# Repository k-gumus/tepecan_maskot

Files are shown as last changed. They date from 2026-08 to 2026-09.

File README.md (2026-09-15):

# Tepecan

Yeditepe IEEE kulübünün resmi maskotu — 3D baskı gövde ve içine giren sesli
asistan. Dinler, sorulanı yapay zekâya iletir, cevabı Türkçe olarak
hoparlöründen söyler.

<p align="center">
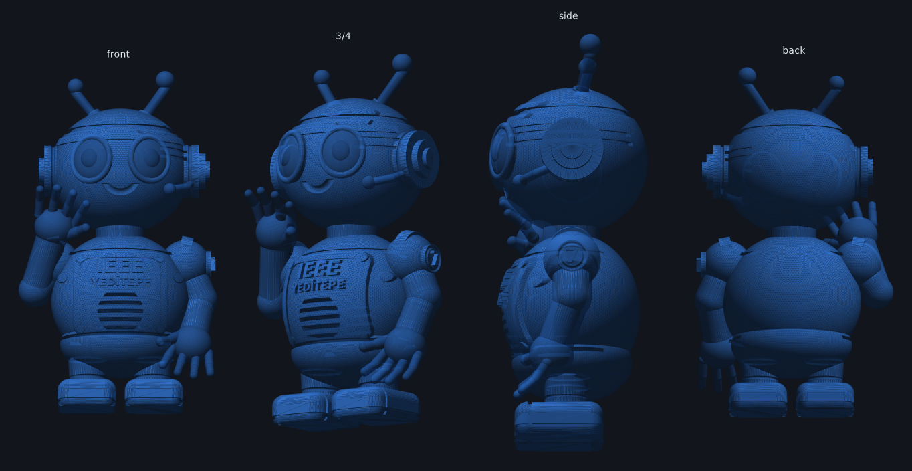
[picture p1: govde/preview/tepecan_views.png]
  
</p>

- **240 mm** boy, tek parça basılan gövde
- Sırtta **vidalı kapak** (73 × 62 mm açıklık), içinde 90 × 75 × 87 mm bölme
- Göğüste kabartma **IEEE** ve **YEDİTEPE**, sol omuzda **7** rozeti
- **"Hey Tepecan"** ile butonsuz tetikleme (yerel, openWakeWord)
- Beyin ağdaki bir PC'de çalışır: **token maliyeti yok, internet gerekmez**

---

## Depoda ne var

```
govde/        3D model — parametrik script, baskıya hazır STL'ler, önizlemeler
yazilim/      esp32/ (maskotun içindeki firmware) ve sunucu/ (ses↔metin↔cevap)
dokuman/      yapım kılavuzu (PDF), bağlantı şeması, üretim scriptleri
```

**Başlarken okunacak tek dosya:** [`dokuman/Tepecan_Yapim_Kilavuzu.pdf`](dokuman/Tepecan_Yapim_Kilavuzu.pdf)
— malzeme listesinden montaja, kuruluma ve sorun gidermeye kadar her şey orada.

---

## Nasıl çalışıyor

```
   MASKOT (ESP32-S3)                       BEYİN SUNUCUSU (bir PC)
   "Hey Tepecan" / buton
   mikrofon kaydeder      ──── Wi-Fi ───▶  /stt    faster-whisper   (ses → metin)
                                           :11434  Ollama, qwen3:4b (cevabı üretir)
   hoparlör çalar         ◀─── Wi-Fi ────  /tts    Piper            (metin → ses)
```

Maskotun içindeki kartın tek işi mikrofonu okuyup hoparlöre yazmak. Ses→metin,
dil modeli ve metin→ses, ağdaki bir bilgisayarda çalışır. Bu yüzden 512 MB
RAM'li küçük bir kart yetiyor ve kullanım başına maliyet oluşmuyor.

Cevap tamamlanmadan konuşmaya başlar: model ilk cümleyi bitirir bitirmez o
cümle seslendirilir, kalanı arka planda üretilir.

<p align="center">
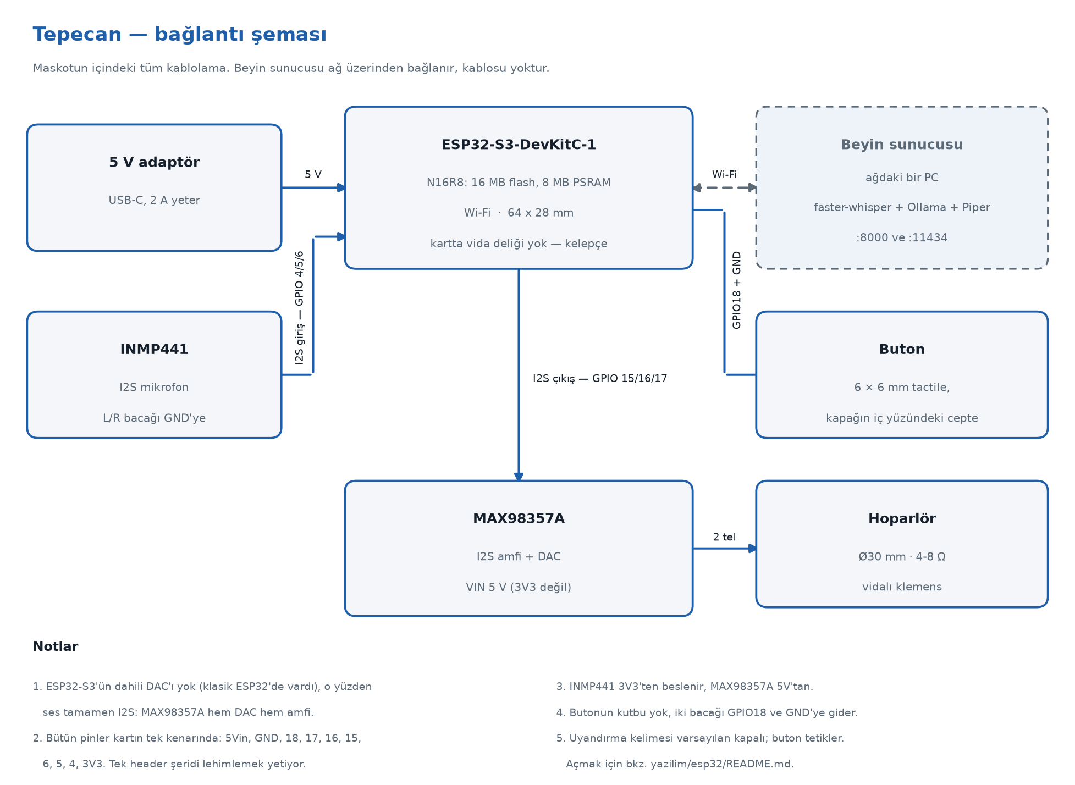
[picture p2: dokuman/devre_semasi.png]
  
</p>

---

## Gövde

```bash
cd govde
pip install -r requirements.txt
python3 tepecan_model.py                 # 240 mm, stl/ klasörünü üretir
python3 tepecan_model.py --height 180    # daha küçük baskı, cidar yine 3 mm
python3 preview_render.py                # önizleme görselleri
python3 dogrula.py                       # elektronik gerçekten sığıyor mu
```

| Dosya | Ne |
|---|---|
| `stl/tepecan_body.stl` | İçi boş gövde — sırt açıklığı, kapak kenarı, vida boss'ları, hoparlör adası, kart kuleleri |
| `stl/tepecan_lid.stl` | Sırt kapağı, baskı pozisyonunda |
| `stl/tepecan_buton.stl` | Kapaktaki butonun kapağı (Ø10 mm başlık, 5 mm sap) |
| `stl/tepecan_plaka.stl` | Kart tepsisi (72 × 36 × 3 mm, ~20 dk) |
| `stl/tepecan_solid.stl` | İçi dolu vitrin figürü (elektronik yoksa bunu bas) |
| `stl/tepesu.stl` | Tepesu: elektroniksiz ikiz, kaldırdığı elinde QR kartı klipsi |

Figür tasarım biriminde modellenip export'ta ölçekleniyor; cidar kalınlığı,
vida delikleri ve kapak boşluğu gibi mutlak kalması gereken ölçüler önce bu
ölçeğe bölünüyor — böylece M3 vida her boyda M3 kalıyor.

Script her STL'i yazdıktan sonra dosyayı geri okuyup kapalı (watertight),
tutarlı normalli, tek parça ve pozitif hacimli olduğunu doğruluyor; geçmezse
hata verip duruyor.

`dogrula.py` bir adım öteye gidiyor: gerçek parçaların zarflarını (65 × 30 × 18 mm
kart, Ø30 mm hoparlör, 6 × 6 × 4.3 mm switch) basılmış STL'in içine yerleştirip
boolean kesişime bakıyor. Sıfır olmayan her kesişim, o parçanın gövdeye girmediği
anlamına geliyor. Hangi kartın alınacağı belli olmadığı için kavitenin kabul
ettiği en büyük kart zarfını da ölçüp yazdırıyor.

**Kart gövdeye kilitli değil.** Gövdede yalnız genel amaçlı dört kule var;
karta özel her şey ayrı basılan `tepecan_plaka.stl` tepsisinde. Kart
değişirse 30-45 saatlik gövde değil, 20 dakikalık tepsi yeniden basılıyor —
`BOARD_HOLE_X` / `BOARD_HOLE_Y` (gerekirse `BOARD_OFFSET_Y`) değiştirilip
yeniden üretiliyor.

| İç ölçü | Değer |
|---|---|
| Kapak açıklığı / geçiş | 73 × 62 mm / 65 × 54 mm |
| Gövde kuleleri | Ø6 mm, 44 × 28 mm aralık (karttan bağımsız), üstleri tabandan 63.8 mm'de |
| Kule kılavuz deliği | Ø2.1 mm × 8 mm (M2.5 kendinden kılavuzlu) |
| Kart tepsisi | 72 × 36 × 3 mm, kart kelepçeyle bağlanıyor |
| Kart için yer | 69.5 × 30, 63.4 × 40-55 mm; tepsi üstünde 40 mm yükseklik |
| Hoparlör yuvası | ızgara Ø30 mm, cep Ø32 mm, düz omuz |
| Kapak vidası | 2 × M3, Ø18.7 mm boss, 12 mm derin |
| Buton | kapakta, Ø4.2 mm delik + 6.6 mm kare cep |
| Kablo yuvası | 15.6 × 7.8 mm, tabandan 38 mm'de |
| Cidar | 3 mm |

**Baskı:** PLA, 0.20 mm katman, 3 perimetre, %10-15 dolgu, ağaç destek açık,
5 mm brim. Z ekseni ≥ 250 mm olan yazıcı gerekiyor.

---

## Yazılım

**Sunucu** (kulüpteki PC):

```bash
curl -fsSL https://ollama.com/install.sh | sh
ollama pull qwen3:4b
OLLAMA_HOST=0.0.0.0 ollama serve

cd yazilim/sunucu
pip install -r requirements.txt
uvicorn beyin:app --host 0.0.0.0 --port 8000
```

**Maskot** — ESP32-S3 (`yazilim/esp32/`, ESP-IDF):

```bash
cd yazilim/esp32
idf.py set-target esp32s3 && idf.py build
idf.py -p /dev/ttyUSB0 flash monitor
```

Wi-Fi bilgisi koda gömülü değil: kart ilk açılışta `Tepecan-Kurulum`
erişim noktasını açıyor, telefondan `http://192.168.4.1` üzerinden ağ ve
sunucu adresi giriliyor. Ayrıntılar ve uyandırma kelimesi modelinin
eğitimi: [`yazilim/esp32/README.md`](yazilim/esp32/README.md).

Sırt kapağındaki **butona bas** — kayıt sen susunca kendiliğinden biter.
**"Hey Tepecan"** ile uyandırma da kodda var ama varsayılan kapalı: ifadeye
özel eğitilmiş bir microWakeWord modeli gerekiyor. Açma yolu ve model eğitimi
[`yazilim/esp32/README.md`](yazilim/esp32/README.md) içinde.

### Ayarlar

| Değişken | Varsayılan | Ne işe yarar |
|---|---|---|
| `TEPECAN_BRAIN` | `http://tepecan-beyin.local` | Beyin sunucusunun adresi |
| `TEPECAN_MODEL` | `qwen3:4b` | Ollama'da kullanılacak model |
| `TEPECAN_LLM_BACKEND` | `ollama` | `ollama` veya `claude` |
| `TEPECAN_BUTTON_PIN` | `17` | Butonun bağlı olduğu GPIO |
| `TEPECAN_WAKE_MODEL` | `~/tepecan/hey_tepecan.onnx` | Uyandırma modeli; yoksa sadece buton |
| `TEPECAN_WAKE_THRESHOLD` | `0.5` | Uyandırma eşiği (yükselt = az yanlış tetikleme) |
| `STT_MODEL` / `STT_DEVICE` | `small` / `cpu` | Sunucuda whisper boyutu ve cihazı |
| `PIPER_MODEL` | `~/piper/tr_TR-dfki-medium.onnx` | Sunucuda Türkçe ses modeli |

### Küçük modelden iyi cevap almak

Model 4 milyar parametreli; ondan bilgiyi *bilmesini* değil, verdiğimiz metni
*okumasını* istiyoruz. Kaliteyi belirleyen sıra:

1. **`yazilim/sunucu/bilgiler.txt` dosyasını doldur.** Kulübe dair her gerçek
   buraya; her soruda modele veriliyor. Doğru cevabı sağlayan asıl mekanizma bu.
2. `persona.txt` içindeki 2-3 cümle sınırını gevşetme — küçük modeller
   uzadıkça dağılır.
3. Hafıza 6 mesajla sınırlı ve 3 dakika sessizlikte sıfırlanıyor; artırma.

---

## Lisans

MIT — bkz. [LICENSE](LICENSE).

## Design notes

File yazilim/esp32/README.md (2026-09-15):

# Tepecan — ESP32-S3 istemcisi

Maskotun içindeki kart. Mikrofonu dinler, uyandırma kelimesini yakalar,
beyin sunucusuna gönderir, gelen cevabı hoparlörden çalar. Ses-metin, dil
modeli ve metin-ses bu kartta değil — hepsi `yazilim/sunucu/beyin.py`'de.

**Donanım:** ESP32-S3-DevKitC-1 N16R8 (16 MB flash, 8 MB PSRAM) ·
INMP441 I2S mikrofon · MAX98357A I2S amfi · Ø30 mm 4 Ω hoparlör ·
6×6 mm tactile switch.

PSRAM şart: kayıt tamponu ve Piper'dan gelen WAV orada duruyor.

## Bağlantılar

| Modül | Bacak | ESP32-S3 |
|---|---|---|
| INMP441 | VDD | 3V3 |
| | GND, L/R | GND |
| | SCK | GPIO4 |
| | WS | GPIO5 |
| | SD | GPIO6 |
| MAX98357A | VIN | **5V** (3V3 değil) |
| | GND | GND |
| | BCLK | GPIO15 |
| | LRC | GPIO16 |
| | DIN | GPIO17 |
| Buton | bacak 1 | GPIO18 |
| | bacak 2 | GND |
| Hoparlör | +/− | MAX98357A çıkışı |

INMP441'in **L/R bacağı GND'ye** gitmeli — sol kanaldan konuşsun diye;
kod da sol kanalı okuyor. Pinleri değiştirmek istersen `main/tepecan.h`.

## Derleme ve yükleme

ESP-IDF v5.1 veya üstü gerekiyor; v5.3 ve v6.1 ile derlendiği doğrulandı.

```bash
idf.py set-target esp32s3
idf.py build
idf.py -p /dev/ttyUSB0 flash monitor
```

> DevKitC-1'de **iki USB-C portu** var (biri native USB, biri UART).
> Yükleme olmazsa diğerini dene — en çok takılınan yer burası.

Windows'ta projeyi **ASCII bir yola** koy (`C:\esp\tepecan` gibi): ESP-IDF
Türkçe karakterli yollarda (`Masaüstü`) takılıyor, OneDrive içinde derlemek de
dosya kilidi sorunları çıkarıyor.

Bağımlılıklar (`esp-tflite-micro`, `esp-nn`, `esp-micro-speech-features`)
`main/idf_component.yml` ile otomatik iniyor, elle bir şey kurmana gerek yok.

## İlk kurulum — bilgisayara gerek yok

Wi-Fi bilgisi koda gömülü değil. Kart kayıtlı ağ bulamazsa kendi erişim
noktasını açıyor:

1. Telefondan **`Tepecan-Kurulum`** ağına bağlan (şifresiz).
2. Tarayıcıda `http://192.168.4.1` aç.
3. Wi-Fi adı, şifresi ve beyin sunucusunun adresini gir.
4. Kaydet — kart yeniden başlayıp o ağa bağlanıyor.

Bilgiler NVS'e yazılıyor, sonraki açılışlarda kendi bağlanıyor. Kulüpten
etkinliğe geçerken ağ değiştirmek için de aynı portal yeter; USB yalnız
ilk yüklemede lazım.

## Uyandırma kelimesi

"Hey Tepecan" modeli depoda **yok**, olamaz da: microWakeWord modelleri
söylenen ifadeye özel eğitiliyor. Kart model dosyası olmadan da çalışır —
o zaman yalnız sırt kapağındaki buton tetikler.

Model eğitmek için:

1. <https://microwakeword.com/train> üzerinden "Hey Tepecan" ifadesini
   eğit (Colab defteri, ücretsiz GPU ile birkaç saat).
2. Çıkan `.tflite` dosyasını `hey_tepecan.tflite` diye adlandır.
3. `model` bölümüne yükle:
   ```bash
   mkdir -p spiffs && cp hey_tepecan.tflite spiffs/
   idf.py storage-flash        # ya da: parttool.py write_partition --partition-name=model
   ```

Dürüst uyarı: microWakeWord'ün kendi belgeleri *"iyi çalışan bir model
eğitmek hâlâ çok zor, ileri seviye kullanıcılar için"* diyor. İlk denemede
tutmayabilir. Yanlış tetikleme çoksa `tepecan.h` içinde `WAKE_ESIK`'i
yükselt (0.85 → 0.92) ya da `WAKE_ARDISIK`'ı 3 yap; hiç tetiklemiyorsa tersi.

Hazır bir modelle zinciri denemek istersen
<https://microwakeword.com/library> altında topluluk modelleri var.

## Ayarlar

Hepsi `main/tepecan.h` içinde: pinler, örnekleme hızı, sessizlik eşiği,
uyandırma eşiği, varsayılan sunucu adresi.

`main/ses.c` içindeki `ses_var_mi()` basit bir RMS eşiği (500) kullanıyor.
Oda gürültülüyse kayıt hiç bitmiyor olabilir — eşiği yükselt. Çok sessizse
ve kayıt erken kesiliyorsa düşür.

## Bilinmesi gerekenler

- **Bu kod donanım üzerinde denenmedi.** Elimde kart yokken yazıldı;
  ilk yüklemede I2S pin/kanal ayarlarında düzeltme gerekebilir. En olası
  yer: INMP441'in kanal seçimi (`MIC_KANAL_SOL`) ve kazanç kaydırması
  (`ses.c` içinde `>> 11`) — ses çok kısık ya da bozuk gelirse orası.
- Beyin sunucusu açık olmalı. Kart ona ulaşamazsa duyar ama cevap veremez.
- MAX98357A pille çalışırken 5 V yerine 3.7-4.2 V görür, ses biraz kısılır.

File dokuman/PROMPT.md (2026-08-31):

# Tepecan için hazır prompt'lar

## 1) AI 3B model araçları (Meshy / Tripo / Sloyd / Rodin) — görselden model

Bu araçlara `reference/tepecan_reference.jpg` görselini **image-to-3D** modunda
yükleyin, ardından açıklama alanına:

> Chibi mascot robot character, full body, standing, with the
> right arm raised in a fist. Big round helmet-like head, two large oval anime
> eyes with raised metallic rims, small curved smile, two thin antennae with
> spherical tips, round headphone/camera discs on both sides of the head.
> Rounded egg-shaped torso with a flat chest panel, short stubby arms with
> mitten fists, short legs with chunky flat-bottomed boots. Smooth hard-surface
> plastic robot toy, closed clean surfaces, no thin fins, no floating parts,
> no text. Single watertight solid, manifold, printable, flat base.
> Style: vinyl designer toy / collectible figurine.

Negatif prompt (destekliyorsa):

> thin fragile parts, floating geometry, holes in surface, open shell,
> hair strands, cloth, sharp spikes, text, logos

Sonrasında **Remesh → Watertight/Solid** ve **Export → STL (mm)** seçin,
yüksekliği 150 mm'ye ölçekleyin. Bu araçlar içi boş bölme ve vida kulağı
üretmez; onu Blender/Fusion/Tinkercad'de eklemek gerekir (bkz. 2. prompt).

## 2) Kod üreten bir asistana (Claude / ChatGPT) — parametrik ve kesin sonuç

> Write a Python script using trimesh + manifold3d that builds a 3D-printable
> chibi mascot robot and exports STL files. Build everything with CSG on
> watertight primitives (icospheres scaled into ellipsoids, capsules, rounded
> boxes made from convex hulls of corner spheres) so the result is manifold.
>
> Figure (design units, Z up, +Y = front): egg-shaped torso ellipsoid
> r=(31,26,30) at z=52 plus a hip ellipsoid r=(27,23,15) at z=32; head
> ellipsoid r=(31,29,28) at z=110; two eye ellipsoids r=(9,7.5,10.5) at
> (±13,21.5,112) with torus rims and raised iris discs; a shallow smile groove
> cut with a torus arc; headphone/camera discs on both sides of the head; a
> microphone boom; two antennae with ball tips and collars; stubby arms with
> ball fists, one raised; short legs with rounded-box boots; the base sliced
> flat at z=2. Natural height ~154 units; scale the exported meshes so the
> printed figure is 240 mm tall.
>
> Add surface detail by intersecting thin offset shells of a body with slabs
> and prisms: a helmet seam and vent lines on the head, a brow ridge, panel
> lines on the belly and chest, ring grooves at every elbow, wrist and knee,
> sole and toe seams on the boots, a raised chest panel with a recessed field
> carrying embossed "IEEE" and "YEDİTEPE", rivet studs, and a numbered badge
> disc on the left shoulder.
>
> Then make an electronics compartment: hollow the torso with an inner
> ellipsoid one wall thickness smaller (wall 3 mm at the printed size), cut a
> 38 x 40 unit rounded opening in the back, add a seating ledge that reaches
> into the opening, add two screw bosses with 2.7 mm pilot holes, and cut a
> cable slot below the opening. Build the cover as the intersection of the
> torso shell with the opening prism shrunk by 0.6 units (0.3 mm clearance per
> side), give it a raised border frame, three vent slots and countersunk
> 3.5 mm clearance holes.
>
> Keep wall thickness, screw holes and cover clearance absolute in mm: divide
> them by the export scale factor before building, so an M3 screw stays M3 at
> any figure height.
>
> Export tepecan_solid.stl (display figure), tepecan_body.stl and
> tepecan_lid.stl (cover rotated flat for printing). Round vertices to float32
> before writing (that is what STL stores), drop the zero-volume shells that
> booleans leave at tangent surfaces, then read each file back and assert it is
> watertight, winding-consistent, a single connected component and of positive
> volume.

Bu depodaki `tepecan_model.py` tam olarak bunun sonucudur; istersen doğrudan
onu çalıştırmak en hızlısı.

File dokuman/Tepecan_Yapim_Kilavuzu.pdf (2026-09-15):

# TEPECAN

# Konuşan maskot — yapım kılavuzu

## 3D baskı gövde · ESP32-S3 · yerel yapay zekâ · Türkçe sesli sohbet

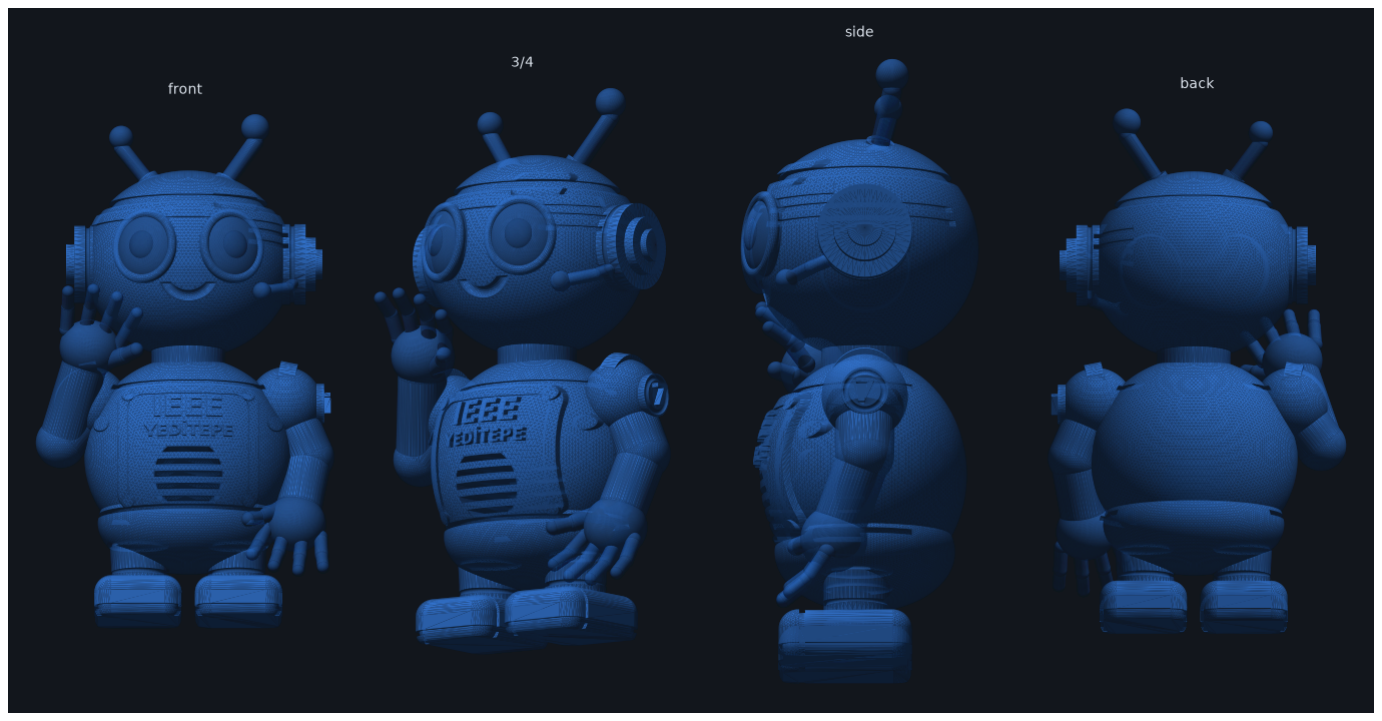
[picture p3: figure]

Tepecan — konuşan maskot yapım kılavuzu | 2

# 1. Ne yapıyoruz

Maskot dinler, sorulanı yapay zekâya iletir, cevabı içindeki hoparlörden Türkçe olarak söyler. Ağır iş maskotun içinde değil, ağdaki bir bilgisayarda çalışır. Maskotun içindeki kartın tek görevi mikrofonu okumak ve hoparlöre yazmak — bu sayede 512 MB RAM'li küçük bir kart yeter ve token maliyeti oluşmaz.

MASKOT (ESP32-S3) | BEYİN SUNUCUSU (bir PC)
───────────────────── | ────────────────────────
butona basılır
mikrofon kaydeder | ──── Wi-Fi ───▶ | /stt | faster-whisper | (ses → metin)
:11434 | Ollama, qwen3:4b (cevabı üretir)
hoparlör çalar | ◀─── Wi-Fi ──── /tts | Piper | (metin → ses)

Cevap tamamlanmadan konuşmaya başlar: model ilk cümleyi bitirir bitirmez o cümle seslendirilir, kalanı arka planda üretilir. Algılanan gecikmeyi yarıya indiren tek değişiklik budur.

## Verilen kararlar ve gerekçeleri

Karar | Neden
Beyin ayrı bir PC'de | Bu sınıf kartlarda 512 MB - 2 GB RAM var; en küçük dil modeli bile zor sığar,
sığsa saniyede 1-3 token üretir. Bir cümle yarım dakika sürerdi.

Büyük kart alınmıyor 85 × 56 mm bir kart maskotun içine girmiyor: kapak açıklığının köşegeni 85.1 mm, o kartın köşegeni 85.8 mm. Kapalı PLA kasada da ısınıyor. Çözdüğü tek darboğaz zaten sunucuya taşındı.

Linux kartı yerine
ESP32-S3

Raspberry Pi de, muadil aarch64 kartlar da Türkiye'de bulunamadı; ESP32-S3 her yerde var ve üçte bir fiyatta. Kart zaten ince istemci olduğu için işletim sistemine ihtiyaç yok: SD kart, açılış süresi ve sürücü avı tamamen kalkıyor.

Ses I2S üzerinden | ESP32-S3'ün dahili DAC'ı yok (klasik ESP32'de vardı, S3'te kaldırıldı), yani
analog çıkış seçenek değil. MAX98357A hem DAC hem amfi olduğu için tek modülle çözülüyor.

Metin → ses de
sunucuda

Piper'ın Türkçe medium sesi Zero 2 W'de gerçek zamandan yavaş kalabiliyor. Sunucuda çalıştırınca bu risk tamamen kalkar, Pi'ye hazır ses gelir.

Model: Qwen3 4B | Küçük modeller arasında çok dilli tarafı güçlü olanlardan; Türkçesi
kullanılabilir. Gemma 3 4B ikinci aday, karşılaştırmaya değer.

Uyandırma kelimesi +
buton

"Hey Tepecan" ile butonsuz tetikleme (openWakeWord, yerel). Metin→ses sunucuya taşındığı için Pi'de yer açıldı. Buton yedek olarak duruyor: gürültülü stantta uyandırmayı kapatıp butona dönebilirsin.

Ollama +
faster-whisper + Piper

Üçü de ücretsiz ve yerel. Zincirin tamamı internetsiz çalışır, kullanım başına maliyet yoktur.

# 2. Malzeme listesi

Fiyatlar kabaca, sadece büyüklük fikri versin diye.

# | Parça | Neden bu | ≈

1 | ESP32-S3-DevKitC-1, N16R8 | Maskotun beyni değil, kulağı ve ağzı: mikrofonu dinler, beyin sunucusuna gönderir, gelen cevabı çalar. N16R8 varyantı şart — 8 MB PSRAM'de kayıt tamponu ve Piper'dan dönen WAV duruyor. 64 × 28 mm, montaj deliği yok (tepsiye kelepçeyle bağlanıyor). | $8
2 | INMP441 I2S mikrofon modülü

Dijital çıkışlı, doğrudan karta bağlanıyor. L/R bacağı GND'ye gider, kod sol kanalı okuyor.

$3

3 MAX98357A I2S amfi modülü

Hem DAC hem 3 W sınıf-D amfi. ESP32-S3'ün dahili DAC'ı olmadığı için sesin analoğa çevrilmesi burada oluyor. VIN 5 V ister, 3V3 değil. Hoparlör çıkışı vidalı klemens — lehim gerekmiyor.

$4

4 | Ø30 mm 4-8 Ω hoparlör | Gövdedeki yuva bu ölçüye göre: ızgara Ø30 mm, oturma omzu Ø32 mm, en fazla 8 mm gövde derinliği. Ø36 sığmıyor — göğüs küresel olduğu için o ayak izinde oturma omzu kartın önüne giriyor. 8 Ω olur, biraz daha kısık çalar. $3

5 5 V 2 A adaptör + USB-C kablo

Telefon şarjı iş görür. Namlu uçlu adaptör ALMA — kart USB-C ile besleniyor.

$5

6 6 × 6 × 4.3 mm tactile switch + ince kablo

Sırt kapağındaki bas-konuş butonu. Uyandırma kelimesi varsayılan kapalı olduğu için şimdilik tek tetikleyici bu. Basılan kapağı (tepecan_buton.stl) sen basıyorsun.

$1

7 M2.5 × 8 mm kendinden kılavuzlu vida (4 adet)

Tepsiyi gövde kulelerine sabitlemek için. Kılavuz delikleri Ø2.1 mm hazır.

$2

8 M3 × 8 kendinden
kılavuzlu vida (2 adet)
Sırt kapağını tutturmak için. Kasada yuvaları hazır. | $1
9 | Plastik kelepçe (2.5 mm, birkaç adet)

Kartı, amfiyi ve mikrofonu tepsiye bağlamak için. Tepside
3.6 mm'lik yuvalar hazır — kartta vida deliği olmadığı için montaj böyle.

$1

10 | Havya + lehim teli | Modüller lehimsiz geliyor. Toplam ~22 nokta: kartta tek header şeridi (bütün kullanılan pinler aynı kenarda), mikrofonda 6, amfide 5. Yarım saatlik iş.
—

11 PLA filament, mavi (~400 g)

Gövde. Güneşte/araçta kalacaksa PETG tercih et. | $12
— | Beyin sunucusu: kulüpte zaten olan bir PC

16 GB RAM yeterli. 8-12 GB VRAM'li bir ekran kartı varsa
cevaplar üç kat hızlanır. Kurulum: yazilim/sunucu/kur.sh

—

Kart alırken N16R8 yazısına dikkat: PSRAM'siz ESP32-S3 varyantları da satılıyor ve onlarda ses tamponları sığmıyor. Klasik ESP32 (S3 değil) da çalışır ama uyandırma kelimesi için S3'ün yapay zekâ komutları lazım. Kartta iki USB-C portu var; yükleme birinde olmazsa diğerini dene.

# 3. Gövde: 3D baskı

## Basılacak dosyalar

Dosya | Ne | Adet
tepecan_body.stl | İçi boş gövde. Sırtta açıklık ve kapak oturma kenarı, iki vida boss'u, hoparlör adası, dört genel amaçlı kart kulesi, kablo yuvası. | 1
tepecan_lid.stl | Sırt kapağı. Havalandırma yarıkları ve havşalı vida delikleriyle, baskı pozisyonunda.
1

tepecan_buton.stl Kapaktaki butonun kapağı: Ø10 mm başlık, 5 mm sap. Yatık basılır, destek istemez. 1

tepecan_plaka.stl Kart tepsisi: altı gövde kulelerine oturur, kart üstüne kelepçeyle bağlanır. 72 × 36 × 3 mm, ~20 dakika. Kart değişirse yalnız bu yeniden basılır.
1
tepecan_solid.stl | İçi dolu vitrin figürü. Elektronik koymayacaksan bunu bas, diğerlerini
| atla.

0-1

## Baskı ayarları

Ayar | Değer | Not
Malzeme | PLA / PLA+ | PETG daha ısıya dayanıklı
Katman | 0.20 mm | Yüz için 0.16 daha temiz
Duvar | 3 perimetre
Dolgu | %10-15 gövde, %20 kapak
Destek | Evet, ağaç/tree, her yerden | Çene altı, kollar, eller, kulaklık diskleri, mikrofon kolu, antenler
Brim | 5 mm | Antenler için
Yönlendirme | Figür ayakta | Taban zaten düzleştirilmiş

Ölçüler: 240 mm boy (anten uçları dahil), 138 mm en, 94 mm derinlik. Z ekseni en az 250 mm

## olan bir yazıcı gerekiyor — Ender 3, P1S, X1C uygun; A1, A1 mini, MK4 gibi 180-210 mm'lik

yazıcılara sığmaz. Kabaca 300-400 g filament ve 30-45 saat. Daha kısa baskı için modeli --height 180 ile yeniden üretebilirsin; cidar 3 mm ve vidalar M3 olarak kalır.

## Gövdedeki elektronik detayları

Bunların hepsi modelde hazır; ölçüler govde/dogrula.py ile her baskı öncesi ölçülüyor.

## - Göğüs ızgarası — Ø30 mm dairesel alan içinde 5 yatay yarık, 2.7 mm yükseklik, merkezi

tabandan 65 mm'de. YEDİTEPE yazısına 3.2 mm pay var.

- Hoparlör yuvası — ızgaranın arkasında düz omuzlu bir ada: göğüs duvarı küresel olduğu için düz yüzlü bir hoparlör ona yaslanamıyor, ada sarkmayı dolduruyor. Cep Ø32 mm, omuz 2.4 mm. Ø40 mm hoparlör bu yüzden sığmıyor: o ayak izinde omuz y = 11.9 mm'ye kadar geriliyor ve kartın önüne giriyor.

## - Kart montaj kuleleri — Ø6 mm, dört adet, karttan bağımsız 44 × 28 mm aralıkta. Üst

yüzeyleri tabandan 63.8 mm'de, tepelerinde M2.5 için Ø2.1 mm kılavuz delik, 8 mm derin. Kartın kendi delik deseni bu kulelerde değil, üstlerine vidalanan tepside.

## - Adaptör plakası — 66 × 36 × 6 mm ayrı parça. Gövdeyi kart seçiminden kurtarıyor: kart

değişirse 30-45 saatlik gövde değil, 20 dakikalık plaka yeniden basılıyor. ESP32-S3-DevKitC-1'de montaj deliği olmadığı için kart vidalanmıyor, kelepçeyle bağlanıyor; köşe yuvalarına da amfi ve mikrofon bağlanıyor.

- Kapak açıklığı — dıştan 73 × 62 mm, oturma kenarından geçiş 65 × 54 mm, köşegen 85 mm. Genişliği kart değil, kartı vidalayan tornavida belirledi: plakadaki vidalar x = ±29 mm'de ve açıklığın alt köşesine yakın; bu ölçüde kenara 3.7 mm kalıyor, tornavida rahat giriyor. Plaka açıklıktan yan yatırılarak geçiyor (köşegen 75 < 85 mm).
- Vida boss'ları — Ø18.7 mm, kavite yüzeyinden 12 mm içeri; M3 vidaya kapak eti ile birlikte 15 mm diş kalıyor.
- Buton yuvası — sırt kapağının iç yüzünde: 6.6 mm kare cep, 4.6 mm derin, önünde 2 mm sap kılavuzu, dışa Ø4.2 mm delik.

## - Kablo yuvası — alt sırtta 15.6 × 7.8 mm, tabandan 38 mm'de; micro-USB fişi kıvrılmadan

geçiyor.

Işıklı gözler denenmedi: RGB LED'leri boyundan geçen bir ışık kanalıyla gözlere taşımak, gözleri şeffaf filamentten ayrı basmayı ve kafayı iki parça yapmayı gerektiriyor. Maskotu en canlı gösterecek şey bu, ama yapımı belirgin zorlaştırdığı için modele girmedi.

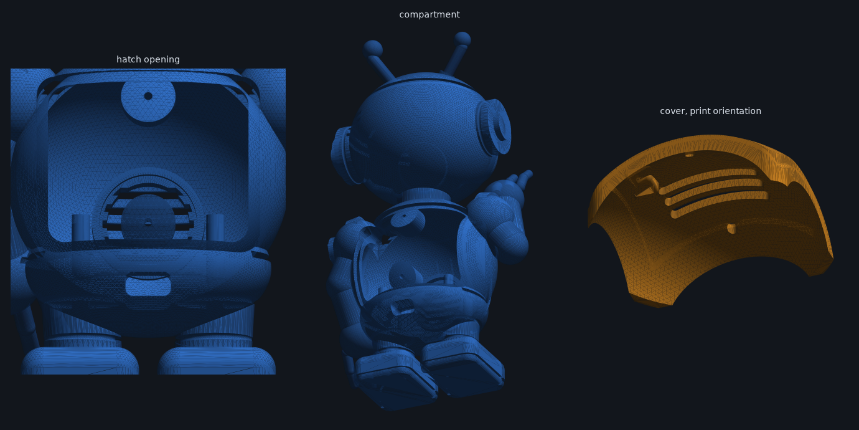
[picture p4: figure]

Soldan: sırt açıklığı ve kapak oturma kenarı; bölmenin dıştan görünüşü; kapak, baskı pozisyonunda (dış yüz yukarı, destek gerekmez).

# 4. İç yerleşim ve montaj

İç boşluk elipsoid olduğu için kutu ölçüsünden cömert: en geniş yerinde 90 × 75 mm, toplam yükseklik 87 mm. Boşluk tabandan 34 mm'de başlıyor, 121 mm'de bitiyor. Aşağıdaki yükseklikler tabandan ölçülü.

ÖN (yüz) | ARKA (kapak)
┌──────────────────────────────────────────────────────┐
│ ╔══════════╗ | | | │
│ ║ HOPARLÖR ║ Ø30 mm, öne bakar, | │ z = 50-80 mm
│ ║ + adası | ║ göğüs ızgarasından konuşur | | │
│ ╚══════════╝ | ┌────────────────────────────────┐ | │
│ | │ ESP32-S3 (64 x 28 mm) | │ | │ z = 67-85 mm
│ | ├────────────────────────────────┤ | │
│ | │ ADAPTÖR PLAKASI | │ | │ z = 64-70 mm
│ | 4 kule ────┴────────────────────────────────┘ | │
│ | z = 34-64 mm | | │
│ | MAX98357A ve INMP441: tepsinin | | │
│ | köşelerine kelepçeyle bağlanır | | │
│ | vida bossu * z=59 mm│
│ | kablo yuvasi -------------------------------> | | │ z = 38 mm
└──────────────────────────────────────────────────────┘

Kart, alt vida bossunun (z = 49.8-68.5 mm) tepesinin üstünde duruyor; bu yüzden arka sınırı boss değil kavite duvarı belirliyor. Sığan en büyük kart: 30 mm derinse 74.5 mm, 40 mm derinse 64.8 mm, 50-55 mm derinse 63.4 mm genişlik (derin kartlar plakada 7-10 mm geriye kaydırılıyor). Plakanın üstünde 40 mm yükseklik var. dogrula.py bu sayıları her baskı öncesi ölçüyor.

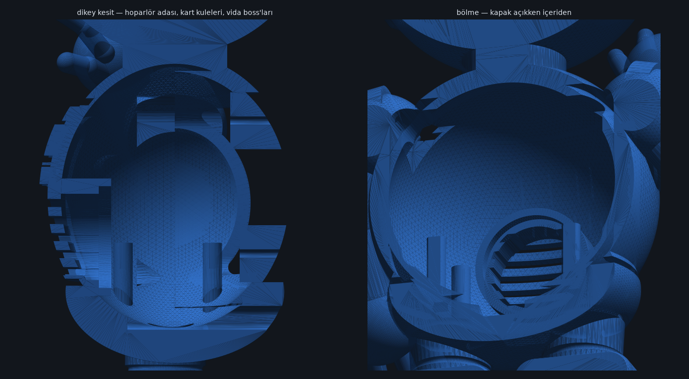
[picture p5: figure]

Solda gövdenin dikey kesiti: kart kuleleri ve hoparlör adası. Sağda kapak açıkken bölmenin içi.

## Montaj sırası

Gövde baskısı karta bağlı değil: plakayı kart gelmeden de basabilirsin, ama delik desenini kartın kendisinden kumpasla ölçüp üretmek en güvenlisi.

- Gövdeyi ve kapağı bas, destekleri temizle. Kapağın açıklığa boşlukla oturduğunu kuru kuruya dene.

## - Kart elindeyken montaj deliklerinin aralığını kumpasla ölç. tepecan_model.py içinde

BOARD_HOLE_X / BOARD_HOLE_Y değerlerini gir (yarı ölçü: 58 × 23 mm delik için 58/2 ve 23/2),

## yeniden üret, tepecan_plaka.stl'i bas. Kart 35 mm'den derinse BOARD_OFFSET_Y ile geriye

kaydır: 50 mm için -7, 55 mm için -10 mm.

- Hoparlörü göğüs ızgarasının arkasındaki adaya, düz omza yüzü öne bakacak şekilde otur ve kenarından yapıştır. Arkasını olabildiğince kapalı tut — omzun çevresini silikonla sızdırmaz yapmak ses kalitesini gözle görülür artırır, bedava kazançtır.
- İşlemcinin üstüne soğutucuyu yapıştır (kartı plakaya vidalamadan önce yap, sonra elin girmez).
- Kartı tepsiye kelepçeyle bağla (kartta vida deliği yok; tepside kartın altından geçen iki sıra yuva var). MAX98357A ve INMP441'i köşe yuvalarına bağla, kabloları kısa kes. Bu işi gövdenin dışında yap — tepsi avucunda dururken çok rahat.
- Hazır plakayı açıklıktan yan yatırarak içeri sok (düz geçmez, köşegen 75 mm) ve dört M2.5 vidayla gövde kulelerine sabitle. Kartın güç girişi kablo yuvasına baksın.
- Hoparlörün iki telini MAX98357A'nın vidalı klemensine sıkıştır.
- Buton kapağını (tepecan_buton.stl) sırt kapağının dışından deliğe geçir. Switch'i kapağın iç yüzündeki cebe, pistonu kapağa bakacak şekilde bastır; sap tam pistona dayanır. İki telini kartın bir GPIO hattına ve GND'ye bağla. Telleri kapağı kapatırken sıkışmayacak kadar uzun bırak.
- Güç kablosunu alt sırttaki yuvadan geçir, karta tak.
- Kapağı iki M3 vidayla kapat. Vidalar havşalı deliklere oturur, başları yüzeyle aynı hizada kalır.

## Kablolama

Nereden | Nereye | Not
INMP441 VDD / GND | Kartın 3V3 ve GND pini | L/R bacağı da GND'ye
INMP441 SCK / WS / SD | GPIO 4 / 5 / 6 | I2S giriş

MAX98357A VIN /
GND
Kartın 5Vin ve GND pini | 5 V ister, 3V3 değil

MAX98357A BCLK /
LRC / DIN
GPIO 15 / 16 / 17 | I2S çıkış
MAX98357A çıkışı | Hoparlör (+/−) | Vidalı klemens, kutup önemsiz
Buton bacak 1 | Bir GPIO hattı | Kodda TEPECAN_BUTTON_PIN / TEPECAN_BUTTON_CHIP
Buton bacak 2 | GND
5 V adaptör | Kartın güç girişi | Varsa veri portuna değil, güç portuna

Kullanılan pinlerin hepsi kartın tek kenarında: 5Vin, GND, 18, 17, 16, 15, 6, 5, 4, 3V3. Yani tek bir header şeridi lehimlemek yetiyor, diğer kenara hiç dokunma.


Bağlantı şeması.

Isı: kapalı PLA kasada bu sınıf bir kart boşta 50-55 °C civarında kalır. Kapaktaki üç yarık ve kablo yuvası hafif hava akışı sağlıyor, soğutucuyla birlikte sorun çıkarmaz. PLA 60 °C dolayında yumuşamaya başlar; maskot güneşte veya araçta kalacaksa gövdeyi PETG bas.

# 5. Beyin sunucusu kurulumu

Kulüpteki herhangi bir PC. Linux varsayılıyor; Windows'ta WSL2 içinde de çalışır.

## Ollama ve model

curl -fsSL https://ollama.com/install.sh | sh
ollama pull qwen3:4b | # ana aday
ollama pull gemma3:4b | # ikinci aday, karşılaştırmak için

# Ağdan erişilebilir olsun diye:

OLLAMA_HOST=0.0.0.0 ollama serve

## Piper (Türkçe ses)

mkdir -p ~/piper && cd ~/piper
# piper çalıştırılabilir dosyasını ve şu ikisini buraya indir:

# | tr_TR-dfki-medium.onnx

# | tr_TR-dfki-medium.onnx.json

echo "Merhaba, ben Tepecan." | ./piper --model tr_TR-dfki-medium.onnx --output_file test.wav
aplay test.wav | # sesi duyuyorsan Piper hazır

## Ses servisi

pip install -r requirements-sunucu.txt uvicorn beyin:app --host 0.0.0.0 --port 8000

# GPU varsa belirgin daha doğru:

STT_DEVICE=cuda STT_MODEL=medium uvicorn beyin:app --host 0.0.0.0 --port 8000

Sunucunun ağdaki adını tepecan-beyin yaparsan Pi tarafında hiçbir ayar değiştirmen gerekmez. Yapamıyorsan Pi'de TEPECAN_BRAIN=http://192.168.1.42 gibi ver.

Kontrol: başka bir makineden curl http://tepecan-beyin.local:8000/health komutu {"ok": true, ...} döndürmeli.

# 6. Maskot (Pi) kurulumu

Raspberry Pi OS Lite, 64 bit. Kurulum sırasında Wi-Fi ve SSH'ı aç.

## Firmware'i yükle

ESP-IDF v5.1 veya üstü gerekiyor. En kolay yol VS Code + Espressif'in ESP-IDF eklentisi; eklenti toolchain'i kendisi kuruyor.

cd yazilim/esp32
idf.py set-target esp32s3
idf.py build
idf.py -p COM3 flash monitor | # Linux'ta /dev/ttyACM0 gibi

## Seri monitörde Tepecan başlıyor ve ardından kayıtlı ağ yok - kurulum noktası açılıyor

görmelisin.

## Ağa bağla — bilgisayara gerek yok

Wi-Fi bilgisi koda gömülü değil, NVS'e yazılıyor. Kart kayıtlı ağ bulamazsa kendi erişim noktasını

## açıyor:

- Telefondan Tepecan-Kurulum ağına bağlan (şifresiz).
- Tarayıcıda http://192.168.4.1 aç.
- Wi-Fi adı, şifresi ve beyin sunucusunun adresini gir (http://sunucunun-IP-adresi:8000).
- Kaydet — kart yeniden başlayıp o ağa bağlanıyor.

Kulüpten etkinliğe geçerken ağ değiştirmek için de aynı portal yeter; USB yalnız ilk yüklemede lazım. Sonrasında prize takılı durduğu sürece çalışır.

Uyandırma kelimesi varsayılan KAPALI geliyor: çalışması için ifadeye özel eğitilmiş bir microWakeWord modeli gerekiyor ve o model depoda yok. Şimdilik sırt kapağındaki buton tetikliyor. Açma yolu ve model eğitimi yazilim/esp32/README.md içinde.

# 7. Ayarlar

## Maskot tarafındakiler yazilim/esp32/main/tepecan.h içinde derleme sabitleri, sunucu

tarafındakiler ortam değişkeni.

Ayar | Varsayılan | Ne işe yarar
PIN_MIC_SCK / WS / SD | 4 / 5 / 6 | Mikrofonun I2S pinleri
PIN_SPK_BCLK / LRC / DIN | 15 / 16 / 17 | Amfinin I2S pinleri
PIN_BUTON | 18 | Butonun bağlı olduğu GPIO
SESSIZLIK_MS | 800 | Bu kadar sessizlikten sonra kayıt biter
EN_UZUN_KAYIT_SN | 10 | Kayıt tavanı
UYANDIRMA_ETKIN | 0 | 1 yapınca uyandırma kelimesi derlenir
WAKE_ESIK | 0.85 | Uyandırma güven eşiği (yükselt = az yanlış tetik)
BEYIN_VARSAYILAN | tepecan-beyin.local:800
| 0 | Kurulum sayfasından değişir
TEPECAN_MODEL | qwen3:4b | Sunucuda: Ollama modeli
STT_MODEL | small | Sunucuda: whisper boyutu (small / medium)
STT_DEVICE | cpu | Sunucuda: cpu veya cuda
PIPER_MODEL | ~/piper/tr_TR-dfki-medi um.onnx | Sunucuda: Türkçe ses

Mikrofon sesi kısık ya da bozuk gelirse yazilim/esp32/main/ses.c içindeki kazanç kaydırmasına (>> 11) ve MIC_KANAL_SOL ayarına bak; donanımda denenmemiş iki nokta bunlar.

# 8. Küçük modelden iyi cevap almanın yolu

Model 4 milyar parametreli. Ondan bilgiyi bilmesini değil, verdiğimiz metni okumasını istiyoruz.

## Kaliteyi belirleyen şey model değil, aşağıdakiler:

- bilgiler.txt dosyasını doldur. Kulübe dair her gerçek buraya. Her soruda modele veriliyor. Doğru cevabı sağlayan asıl mekanizma bu — en yüksek getirili iş, modeli değiştirmek değil bu dosyayı yazmaktır.
- 2-3 cümle sınırını gevşetme. persona.txt bunu dayatıyor. Küçük modeller uzadıkça dağılır, üstelik hoparlörden uzun cevap dinlemek sıkıcıdır.
- Hafızayı artırma. Altı mesaj tutuluyor, üç dakika sessizlikte sıfırlanıyor. Uzun geçmiş küçük modelde kaliteyi düşürür.

## - repeat_penalty 1.15 kendini tekrarlama döngüsünü kesiyor, num_predict 160 cevabı kısa

tutuyor.

## - Qwen3 düşünme modunda <think> etiketi üretebiliyor; hem kapatılıyor hem de metinden

temizleniyor. Yoksa hoparlör modelin iç monologunu okur.

- Model seçimini ölçerek yap: aynı on soruyu qwen3:4b ve gemma3:4b'ye sor, kulüpten birkaç kişiyle kör karşılaştır. Bir akşamlık iş, kararı bitirir.

# 9. Test ve sorun giderme

Belirti | Muhtemel sebep | Ne yapmalı
Hiç ses kaydedilmiyor | Yanlış ses cihazı seçili | arecord -l ve python3 -m sounddevice ile USB kartını bul, TEPECAN_MIC'e yaz
Buton çalışmıyor | gpiozero yalnız Raspberry Pi'de çalışır | python-periphery kurulu mu bak; TEPECAN_BUTTON_CHIP ve TEPECAN_BUTTON_PIN'i kartının pin haritasına göre ayarla
Kayıt hemen bitiyor | VAD gürültüyü konuşma sanıyor ya da mikrofon sessiz | alsamixer ile giriş seviyesini yükselt; kodda Vad(2) yerine Vad(1) dene
Kayıt hiç bitmiyor | Ortam gürültülü, sessizlik algılanmıyor

Vad(3) yap; SILENCE_MS değerini 600'e düşür

STT hatası /
bağlanamıyor

Sunucu adresi yanlış veya
güvenlik duvarı

karttan curl
http://tepecan-beyin.local:8000/health dene

Cevap geliyor ama
ses yok

Piper modeli sunucuda
bulunamıyor

Sunucu günlüğüne bak; PIPER_MODEL yolunu tam ver

Ses cızırtılı, kesik | Adaptör zayıf | 5 V 3 A adaptör kullan; powerbank'ten besleme
Model saçmalıyor, konuyu kaçırıyor | bilgiler.txt boş ya da çok uzun | Doldur ama 1500 karakteri geçme
Cevaplar çok yavaş | Sunucuda GPU yok | Daha küçük model (qwen3:1.7b) veya STT_MODEL=base dene
Hoparlörden model düşüncesi okunuyor | <think> etiketi sızmış | Ollama sürümünü güncelle; think:false destekli olmalı
Durmadan kendi kendine uyanıyor | Uyandırma eşiği düşük, ortam gürültülü | TEPECAN_WAKE_THRESHOLD=0.6, sonra TEPECAN_WAKE_HITS=3
Uyandırma kelimesine hiç tepki vermiyor | Eşik yüksek, mikrofon kısık ya da model yolu yanlış | Açılıştaki "Uyandırma kelimesi hazır" satırını gör; eşiği 0.4 yap

## Beklenen gecikme

Sunucu | Soru sonundan ilk sese
Ekran kartlı PC (8-12 GB VRAM) | yaklaşık 2-3 saniye
Ekran kartsız PC, qwen3:4b | yaklaşık 5-7 saniye
Ekran kartsız PC, qwen3:1.7b | yaklaşık 3-4 saniye

# 10. Kodlar

## yazilim/sunucu/beyin.py — beyin sunucusu (ses↔metin)

#!/usr/bin/env python3

"""
Tepecan beyin sunucusu — ses->metin ve metin->ses.

Bu işler maskotun içindeki ESP32 için fazla ağır; buraya alındı. LLM ayrı bir servis (Ollama) olarak aynı makinede çalışır, sunucu ona bağlanır.

uvicorn beyin:app --host 0.0.0.0 --port 8000

Ortam değişkenleri:
STT_MODEL=small | CPU'da makul, Türkçesi iyi (varsayılan)
STT_DEVICE=cuda | GPU varsa
PIPER_MODEL=/yol/tr_TR-dfki-medium.onnx
"""

import os
import pathlib
import subprocess
import tempfile

import requests
from fastapi import FastAPI, File, Request, UploadFile from fastapi.responses import Response
from pydantic import BaseModel
from faster_whisper import WhisperModel

STT_MODEL = os.getenv("STT_MODEL", "small")
STT_DEVICE = os.getenv("STT_DEVICE", "cpu")
STT_COMPUTE = os.getenv("STT_COMPUTE", "int8" if STT_DEVICE == "cpu" else "float16")

OLLAMA_URL = os.getenv("OLLAMA_URL", "http://127.0.0.1:11434")
OLLAMA_MODEL = os.getenv("TEPECAN_MODEL", "qwen3:4b")

PIPER_BIN = os.getenv("PIPER_BIN", "piper")
PIPER_MODEL = os.getenv("PIPER_MODEL",
| os.path.expanduser("~/piper/tr_TR-dfki-medium.onnx"))

BURASI = pathlib.Path(__file__).resolve().parent

def _oku(ad, yedek=""):
try:
return (BURASI / ad).read_text(encoding="utf-8").strip() except OSError:
return yedek

PERSONA = _oku("persona.txt", "Sen Tepecan'sın, Yeditepe IEEE kulübünün maskotu.") BILGILER = _oku("bilgiler.txt")

print(f"faster-whisper yükleniyor: {STT_MODEL} ({STT_DEVICE}/{STT_COMPUTE})") whisper = WhisperModel(STT_MODEL, device=STT_DEVICE, compute_type=STT_COMPUTE) print("Hazır.")

app = FastAPI(title="Tepecan beyin")

@app.get("/health")
def health():
return {"ok": True, "stt": STT_MODEL, "device": STT_DEVICE}

def _cozumle(wav_baytlari: bytes) -> str:
with tempfile.NamedTemporaryFile(suffix=".wav") as tmp: tmp.write(wav_baytlari)
tmp.flush()
segments, info = whisper.transcribe(
tmp.name,
language="tr", | # dili sabitlemek tahmin adımını atlatır, hızlandırır
vad_filter=True,
beam_size=1, | # sohbet için hız > son kırıntı doğruluk

)
text = " ".join(s.text.strip() for s in segments).strip()

print(f"STT [{info.duration:.1f} sn]: {text}")
return text

@app.post("/stt")
async def stt(audio: UploadFile = File(...)):
"""WAV dosya yüklemesi al, Türkçe metin döndür (Python istemcisi).""" return {"text": _cozumle(await audio.read())}

@app.post("/stt-raw")
async def stt_raw(request: Request):
"""Ham WAV gövdesi al, Türkçe metin döndür.

ESP32 için: mikrodenetleyicide multipart/form-data kurmak gereksiz zahmet, gövdeye doğrudan WAV koyup göndermek yetiyor.
"""
return {"text": _cozumle(await request.body())}

class SohbetIstek(BaseModel):
text: str

@app.post("/chat")
def chat(istek: SohbetIstek):
"""Soruyu Ollama'ya sor, cevabı düz metin olarak döndür.

Akan JSON'u ayrıştırmayı ve cümlelere bölmeyi burada yapıyoruz; ESP32'ye yaptırmak gereksiz karmaşıklık. Kart yalnız soruyu yollayıp cevabı alıyor.
"""
mesajlar = [{"role": "system", "content": PERSONA + "\n\n" + BILGILER}, {"role": "user", "content": istek.text}]
r = requests.post(
f"{OLLAMA_URL}/api/chat",
json={"model": OLLAMA_MODEL, "messages": mesajlar, "stream": False, "options": {"temperature": 0.7, "num_predict": 200}}, timeout=120,
)
r.raise_for_status()
cevap = r.json().get("message", {}).get("content", "").strip()

# qwen3 gibi modeller düşünme bloğu yazabiliyor; seslendirmeden önce at. if "</think>" in cevap:

cevap = cevap.split("</think>", 1)[1].strip()

print(f"LLM: {cevap[:80]}")
return {"text": cevap}

class TTSIstek(BaseModel): text: str

@app.post("/tts")
def tts(istek: TTSIstek):
"""Metin al, WAV döndür. Piper burada çalışır, Pi'de değil."""
with tempfile.NamedTemporaryFile(suffix=".wav") as tmp: subprocess.run(
[PIPER_BIN, "--model", PIPER_MODEL, "--output_file", tmp.name], input=istek.text.encode("utf-8"),
stdout=subprocess.DEVNULL, stderr=subprocess.DEVNULL, check=True,
)
tmp.seek(0)
wav = open(tmp.name, "rb").read()

print(f"TTS [{len(wav)/1024:.0f} KB]: {istek.text[:60]}") return Response(content=wav, media_type="audio/wav")

## yazilim/esp32/main/tepecan.h — ayarlar ve pinler

/* Tepecan - ESP32-S3 istemcisi, ortak ayarlar.
*
* Kart: ESP32-S3-DevKitC-1 N16R8 (16 MB flash, 8 MB PSRAM).
* Ses: INMP441 (I2S mikrofon) + MAX98357A (I2S amfi).
*
* Ağır iş burada değil: ses-metin, dil modeli ve metin-ses ağdaki beyin
* sunucusunda (yazilim/sunucu/beyin.py) çalışıyor. Bu kartın işi mikrofonu * okumak, uyandırma kelimesini yakalamak ve hoparlöre yazmak.
*/
#pragma once

#include <stdbool.h>

#include <stdint.h>

/* ---------------------------------------------------------------- pinler */ /* TFT yok, bu yüzden S3'ün hemen bütün GPIO'ları serbest. Aşağıdakiler
* DevKitC-1'de header'a çıkan, açılışta özel anlamı olmayan hatlar. */
#define PIN_MIC_SCK | 4 | /* INMP441 SCK | (bit clock) | */

#define PIN_MIC_WS | 5 | /* INMP441 WS | (word select) */

#define PIN_MIC_SD | 6 | /* INMP441 SD | (veri çıkışı) */

#define PIN_SPK_BCLK | 15 | /* MAX98357A BCLK */

#define PIN_SPK_LRC | 16 | /* MAX98357A LRC | */

#define PIN_SPK_DIN | 17 | /* MAX98357A DIN | */

#define PIN_BUTON | 18 | /* kapaktaki tactile switch, diğer bacak GND */

/* INMP441'in L/R bacağı GND'ye bağlıysa sol kanaldan konuşur. */
#define MIC_KANAL_SOL true

/* ----------------------------------------------------------------- ses */
#define ORNEK_HZ | 16000 | /* STT, VAD ve uyandırma modeli 16 kHz ister */

#define BLOK_ORNEK | 320 | /* 20 ms - webrtcvad ve mWW ile uyumlu | */

#define EN_UZUN_KAYIT_SN | 10 | /* bundan sonrası kesiliyor | */

#define SESSIZLIK_MS | 800 | /* bu kadar sessizlikten sonra kayıt biter | */

/* ------------------------------------------------------------- uyandırma */ /* Uyandırma kelimesi varsayılan olarak KAPALI. Açmak için:
* | 1. Burayı 1 yap.
* | 2. main/idf_component.yml içindeki üç bağımlılığın yorumunu kaldır.
* | 3. Eğitilmiş modeli "model" bölmesine yükle (bkz. README).
*
* Kapalı geliyor çünkü model dosyası olmadan zaten çalışmıyor, ve açıkken * derleme kayıt sunucusundan üç bileşen indirmeye çalışıyor. Kapalıyken
* proje kutudan çıktığı gibi derleniyor; buton tetikleyici olarak yeterli. *
* DİKKAT: uyandirma.cc donanımda denenmedi. microWakeWord'ün beklediği
* öznitelik çıkarıcı (eski "microfrontend" API'si) güncel esp-tflite-micro * sürümlerinde yok, ayrı bir bileşen olarak geliyor - açtığında derleme
* hatası alırsan ilk bakılacak yer orası.
*/
#define UYANDIRMA_ETKIN 0

/* microWakeWord modeli SPIFFS'te. Dosya yoksa program çalışır, yalnız
* buton tetikler - uyandırma kelimesi sessizce devre dışı kalır. */
#define WAKE_MODEL_YOLU | "/model/hey_tepecan.tflite"

#define WAKE_ESIK | 0.85f | /* 0..1, yükseltmek yanlış tetiklemeyi azaltır */

#define WAKE_ARDISIK | 2 | /* üst üste kaç pencere eşiği geçmeli | */

/* ------------------------------------------------------------------- ağ */ #define BEYIN_VARSAYILAN "http://tepecan-beyin.local:8000"
#define HTTP_ZAMAN_ASIMI_MS 60000

/* ---------------------------------------------------------------- durum */ typedef enum {
DURUM_BEKLIYOR, | /* uyandırma kelimesi ya da buton bekleniyor */
DURUM_DINLIYOR, | /* kayıt sürüyor | */
DURUM_DUSUNUYOR, | /* sunucu cevap üretiyor | */
DURUM_KONUSUYOR, | /* hoparlör çalıyor | */
DURUM_HATA,
} tepecan_durum_t;

void durum_yaz(tepecan_durum_t d);
const char *durum_adi(tepecan_durum_t d);

## yazilim/esp32/main/main.c — akış

/* Tepecan - ESP32-S3 istemcisi.
*
* | uyandırma kelimesi ya da buton
* | -> kayıt (sen susunca biter)
* | -> /stt-raw | (ses | -> metin)
* | -> /chat | (metin -> cevap)
* | -> /tts | (cevap -> ses)
* | -> hoparlör
*
* Bütün ağır iş beyin sunucusunda. Burada yalnız akış ve zamanlama var. */
#include "tepecan.h"

#include "ses.h"

#include "ag.h"

#include "uyandirma.h"

#include <string.h>

#include <stdlib.h>

#include "driver/gpio.h"

#include "esp_log.h"

#include "esp_heap_caps.h" #include "esp_spiffs.h"

#include "freertos/FreeRTOS.h" #include "freertos/task.h"

static const char *ETIKET = "tepecan";
static tepecan_durum_t g_durum = DURUM_BEKLIYOR;

const char *durum_adi(tepecan_durum_t d)
{
| switch (d) {
case DURUM_BEKLIYOR: | return "bekliyor";
case DURUM_DINLIYOR: | return "dinliyor";
case DURUM_DUSUNUYOR: return "düşünüyor"; case DURUM_KONUSUYOR: return "konuşuyor";
| default: | | return "hata";
}
}

void durum_yaz(tepecan_durum_t d) {
if (d == g_durum) return;
| g_durum = d;
ESP_LOGI(ETIKET, "durum: %s", durum_adi(d));
}

/* ------------------------------------------------------------------ WAV */ /* 44 baytlık standart başlık; whisper tarafında sorunsuz açılıyor. */ static void wav_basligi(uint8_t *b, uint32_t veri_boy, uint32_t hz)
{
uint32_t bayt_hz = hz * 2;
memcpy(b, "RIFF", 4);
uint32_t riff = 36 + veri_boy; memcpy(b + 4, &riff, 4);
memcpy(b + 8, "WAVEfmt ", 8);
uint32_t fmt = 16; | memcpy(b + 16, &fmt, 4);
uint16_t pcm = 1, kanal = 1; | memcpy(b + 20, &pcm, 2); memcpy(b + 22, &kanal, 2);
memcpy(b + 24, &hz, 4);
memcpy(b + 28, &bayt_hz, 4);
uint16_t hiza = 2, bit = 16; | memcpy(b + 32, &hiza, 2); memcpy(b + 34, &bit, 2);
memcpy(b + 36, "data", 4); | memcpy(b + 40, &veri_boy, 4);
}

/* Gelen WAV'ın veri bölümünü ve örnekleme hızını bul. */
static const int16_t *wav_coz(const uint8_t *wav, size_t boy,
| | | size_t *ornek, uint32_t *hz)
{
if (boy < 44 || memcmp(wav, "RIFF", 4) != 0) return NULL; memcpy(hz, wav + 24, 4);
| size_t p = 12;
while (p + 8 <= boy) {
uint32_t parca_boy;
memcpy(&parca_boy, wav + p + 4, 4);
if (memcmp(wav + p, "data", 4) == 0) {
if (p + 8 + parca_boy > boy) parca_boy = boy - p - 8;

*ornek = parca_boy / 2;
return (const int16_t *)(wav + p + 8); }
p += 8 + parca_boy + (parca_boy & 1);
}
return NULL;
}

/* ---------------------------------------------------------------- buton */ static void buton_kur(void)
{
gpio_config_t c = {
.pin_bit_mask = 1ULL << PIN_BUTON, .mode = GPIO_MODE_INPUT,
.pull_up_en = GPIO_PULLUP_ENABLE, .pull_down_en = GPIO_PULLDOWN_DISABLE, .intr_type = GPIO_INTR_DISABLE,
};
gpio_config(&c);
}

static bool buton_basili(void) { return gpio_get_level(PIN_BUTON) == 0; }

/* ---------------------------------------------------------------- akış */ /* Tetik gelene kadar dinler. Dönen değer: "buton" ya da "kelime". */ static const char *tetik_bekle(void)
{
static int16_t blok[BLOK_ORNEK];
uyandirma_sifirla();
while (true) {
if (mik_oku(blok, BLOK_ORNEK) != ESP_OK) continue;

if (buton_basili()) {
while (buton_basili()) vTaskDelay(pdMS_TO_TICKS(20)); return "buton";
}
if (uyandirma_dinle(blok, BLOK_ORNEK)) return "kelime"; }
}

/* Sen susana kadar kaydeder. WAV'ı PSRAM'de döndürür. */ static uint8_t *sessizlige_kadar_kaydet(size_t *wav_boy)
{
const size_t en_cok = (size_t)ORNEK_HZ * EN_UZUN_KAYIT_SN;
uint8_t *wav = heap_caps_malloc(44 + en_cok * 2, MALLOC_CAP_SPIRAM);
if (!wav) { ESP_LOGE(ETIKET, "kayıt için PSRAM yetmedi"); return NULL; }

int16_t *veri = (int16_t *)(wav + 44);
size_t yazilan = 0;
int sessiz_blok = 0;
const int sessiz_sinir = SESSIZLIK_MS / (BLOK_ORNEK * 1000 / ORNEK_HZ); bool konusma_basladi = false;

while (yazilan + BLOK_ORNEK <= en_cok) {
if (mik_oku(veri + yazilan, BLOK_ORNEK) != ESP_OK) break; bool ses = ses_var_mi(veri + yazilan, BLOK_ORNEK); yazilan += BLOK_ORNEK;

if (ses) { konusma_basladi = true; sessiz_blok = 0; }
else if (konusma_basladi && ++sessiz_blok >= sessiz_sinir) break; /* Hiç konuşma başlamadıysa 3 saniye sonra vazgeç. */
else if (!konusma_basladi && yazilan > (size_t)ORNEK_HZ * 3) { free(wav);
return NULL;
}
}
if (!konusma_basladi) { free(wav); return NULL; }

wav_basligi(wav, yazilan * 2, ORNEK_HZ);
*wav_boy = 44 + yazilan * 2;
ESP_LOGI(ETIKET, "kayıt bitti: %.1f sn", (float)yazilan / ORNEK_HZ); return wav;
}

static void konus(const char *metin) {

size_t wav_boy = 0;
uint8_t *wav = beyin_tts(metin, &wav_boy); if (!wav) return;

size_t ornek = 0;
uint32_t hz = ORNEK_HZ;
const int16_t *pcm = wav_coz(wav, wav_boy, &ornek, &hz); if (pcm) {
durum_yaz(DURUM_KONUSUYOR);
hoparlor_cal(pcm, ornek, hz);
}
free(wav);
}

static void tur(void)
{
durum_yaz(DURUM_BEKLIYOR);
mik_bosalt();
const char *nasil = tetik_bekle(); ESP_LOGI(ETIKET, "(%s ile uyandı)", nasil);

durum_yaz(DURUM_DINLIYOR);
size_t wav_boy = 0;
uint8_t *wav = sessizlige_kadar_kaydet(&wav_boy);
if (!wav) return;

/* Bundan sonrası mikrofonu gerektirmiyor. Kapatmak Tepecan'ın kendi * sesini duymasını da engelliyor. */
mik_duraklat();
durum_yaz(DURUM_DUSUNUYOR);

char *soru = beyin_stt(wav, wav_boy); free(wav);
if (!soru || soru[0] == '\0') { free(soru);
mik_devam();
return;
}
ESP_LOGI(ETIKET, "sen: %s", soru);

char *cevap = beyin_chat(soru); free(soru);
if (cevap) {
ESP_LOGI(ETIKET, "tepecan: %s", cevap); konus(cevap);
free(cevap);
}
mik_devam();
}

/* ----------------------------------------------------------------- giriş */ static void spiffs_bagla(void)
{
esp_vfs_spiffs_conf_t c = {
.base_path = "/model",
.partition_label = "model", .max_files = 2,
.format_if_mount_failed = true,
};
esp_err_t r = esp_vfs_spiffs_register(&c);
if (r != ESP_OK) ESP_LOGW(ETIKET, "SPIFFS bağlanamadı: %s", esp_err_to_name(r)); }

void app_main(void)
{
ESP_LOGI(ETIKET, "Tepecan başlıyor"); buton_kur();
spiffs_bagla();
ESP_ERROR_CHECK(ses_baslat());

esp_err_t r = ag_baslat();
if (r == ESP_ERR_NOT_FINISHED) {
/* Kurulum portalı açık; kullanıcı ağ bilgisini girince kart kendi * yeniden başlıyor. Burada beklemekten başka yapacak iş yok. */ while (true) vTaskDelay(pdMS_TO_TICKS(1000));
}

if (r != ESP_OK) ESP_LOGW(ETIKET, "ağa bağlanılamadı, denemeye devam");

if (!uyandirma_baslat(WAKE_MODEL_YOLU))
ESP_LOGW(ETIKET, "uyandırma kelimesi kapalı - yalnız buton tetikler");

ESP_LOGI(ETIKET, "hazır. beyin: %s", beyin_adresi());
while (true) tur();
}

## yazilim/esp32/main/ses.c — I2S mikrofon ve hoparlör

#include "ses.h"

#include "tepecan.h"

#include <string.h>

#include <math.h>

#include "driver/i2s_std.h" #include "esp_log.h"

#include "freertos/FreeRTOS.h" #include "freertos/task.h"

static const char *ETIKET = "ses";

static i2s_chan_handle_t mik_kanal; static i2s_chan_handle_t hop_kanal;
static bool mik_acik;

/* INMP441 24 bitlik veriyi 32 bitlik yuvada gönderiyor; 32 bit okuyup * yukarı hizalanmış 16 biti alıyoruz. */
#define MIK_YUVA I2S_DATA_BIT_WIDTH_32BIT

static esp_err_t mikrofon_kur(void)
{
i2s_chan_config_t kanal = I2S_CHANNEL_DEFAULT_CONFIG(I2S_NUM_0, I2S_ROLE_MASTER); kanal.dma_desc_num = 6;
kanal.dma_frame_num = BLOK_ORNEK;
kanal.auto_clear = true;
ESP_ERROR_CHECK(i2s_new_channel(&kanal, NULL, &mik_kanal));

i2s_std_config_t std = {
.clk_cfg = I2S_STD_CLK_DEFAULT_CONFIG(ORNEK_HZ), .slot_cfg = I2S_STD_PHILIPS_SLOT_DEFAULT_CONFIG( MIK_YUVA, I2S_SLOT_MODE_MONO),
.gpio_cfg = {
.mclk = I2S_GPIO_UNUSED,
.bclk = PIN_MIC_SCK,
.ws = PIN_MIC_WS,
.dout = I2S_GPIO_UNUSED,
.din = PIN_MIC_SD,
.invert_flags = { false, false, false },
},
};
std.slot_cfg.slot_mask = MIC_KANAL_SOL ? I2S_STD_SLOT_LEFT : I2S_STD_SLOT_RIGHT; ESP_ERROR_CHECK(i2s_channel_init_std_mode(mik_kanal, &std)); ESP_ERROR_CHECK(i2s_channel_enable(mik_kanal));
mik_acik = true;
return ESP_OK;
}

static esp_err_t hoparlor_kur(void)
{
i2s_chan_config_t kanal = I2S_CHANNEL_DEFAULT_CONFIG(I2S_NUM_1, I2S_ROLE_MASTER); kanal.dma_desc_num = 8;
kanal.dma_frame_num = 240;
kanal.auto_clear = true;
ESP_ERROR_CHECK(i2s_new_channel(&kanal, &hop_kanal, NULL));

i2s_std_config_t std = {
.clk_cfg = I2S_STD_CLK_DEFAULT_CONFIG(ORNEK_HZ), .slot_cfg = I2S_STD_PHILIPS_SLOT_DEFAULT_CONFIG( I2S_DATA_BIT_WIDTH_16BIT, I2S_SLOT_MODE_MONO), .gpio_cfg = {
.mclk = I2S_GPIO_UNUSED,
.bclk = PIN_SPK_BCLK,
.ws = PIN_SPK_LRC,
.dout = PIN_SPK_DIN,
.din = I2S_GPIO_UNUSED,
.invert_flags = { false, false, false },
},
};
ESP_ERROR_CHECK(i2s_channel_init_std_mode(hop_kanal, &std)); return ESP_OK;
}

esp_err_t ses_baslat(void)

{
ESP_ERROR_CHECK(mikrofon_kur()); ESP_ERROR_CHECK(hoparlor_kur());
ESP_LOGI(ETIKET, "I2S hazır: mik %d/%d/%d, hoparlör %d/%d/%d", PIN_MIC_SCK, PIN_MIC_WS, PIN_MIC_SD,
PIN_SPK_BCLK, PIN_SPK_LRC, PIN_SPK_DIN);
return ESP_OK;
}

esp_err_t mik_oku(int16_t *hedef, size_t ornek) {
static int32_t ham[BLOK_ORNEK];
size_t okundu = 0;
if (ornek > BLOK_ORNEK) ornek = BLOK_ORNEK;

esp_err_t r = i2s_channel_read(mik_kanal, ham, ornek * sizeof(int32_t), &okundu, portMAX_DELAY);
if (r != ESP_OK) return r;

size_t n = okundu / sizeof(int32_t);
for (size_t i = 0; i < n; i++) {
/* INMP441: anlamlı 24 bit üstte. 16 bite indirmek için 11 kaydırıp * (8 bit hizalama + 3 bit kazanç) taşmaya karşı kırpıyoruz. */ int32_t v = ham[i] >> 11;
if (v > 32767) v = 32767;
if (v < -32768) v = -32768;
hedef[i] = (int16_t)v;
}
for (size_t i = n; i < ornek; i++) hedef[i] = 0; return ESP_OK;
}

void mik_duraklat(void)
{
if (mik_acik) { i2s_channel_disable(mik_kanal); mik_acik = false; } }

void mik_devam(void)
{
if (!mik_acik) { i2s_channel_enable(mik_kanal); mik_acik = true; } }

void mik_bosalt(void)
{
/* Tetikten önce biriken sesi at, yoksa kayıt eski gürültüyle başlıyor. */ static int16_t cop[BLOK_ORNEK];
for (int i = 0; i < 8; i++) mik_oku(cop, BLOK_ORNEK);
}

esp_err_t hoparlor_cal(const int16_t *pcm, size_t ornek, uint32_t hz)
{
/* Sunucudan gelen WAV 22.05 kHz olabiliyor (Piper), mikrofon 16 kHz. * Kanalı çalmadan önce o hıza ayarlıyoruz. */
i2s_std_clk_config_t saat = I2S_STD_CLK_DEFAULT_CONFIG(hz); ESP_ERROR_CHECK(i2s_channel_disable(hop_kanal)); ESP_ERROR_CHECK(i2s_channel_reconfig_std_clock(hop_kanal, &saat)); ESP_ERROR_CHECK(i2s_channel_enable(hop_kanal));

size_t yazildi = 0;
esp_err_t r = i2s_channel_write(hop_kanal, pcm, ornek * sizeof(int16_t), &yazildi, portMAX_DELAY);
/* Son tamponun gerçekten çıkması için kısa bir bekleme; hemen disable * edersek cümlenin sonu kesiliyor. */
vTaskDelay(pdMS_TO_TICKS(60));
i2s_channel_disable(hop_kanal);
return r;
}

bool ses_var_mi(const int16_t *blok, size_t ornek)
{
int64_t kare = 0;
for (size_t i = 0; i < ornek; i++) kare += (int32_t)blok[i] * blok[i]; double rms = sqrt((double)kare / (double)ornek);
return rms > 500.0; | /* sessiz oda ~100-200, konuşma >1000 */
}

## yazilim/esp32/main/ag.c — Wi-Fi ve beyin sunucusu istemcisi

#include "ag.h"

#include "tepecan.h"

#include <string.h>

#include <stdlib.h>

#include "esp_log.h"

#include "esp_wifi.h"

#include "esp_netif.h"

#include "esp_event.h"

#include "esp_http_client.h" #include "esp_heap_caps.h" #include "nvs_flash.h"

#include "nvs.h"

#include "cJSON.h"

#include "freertos/FreeRTOS.h" #include "freertos/event_groups.h"

static const char *ETIKET = "ag";
static EventGroupHandle_t olaylar;
#define BIT_BAGLANDI BIT0

static char g_beyin[128] = BEYIN_VARSAYILAN;
static bool g_bagli;

/* ------------------------------------------------------------------ NVS */ static esp_err_t nvs_oku(const char *anahtar, char *hedef, size_t boy)
{
nvs_handle_t h;
if (nvs_open("tepecan", NVS_READONLY, &h) != ESP_OK) return ESP_FAIL; esp_err_t r = nvs_get_str(h, anahtar, hedef, &boy);
nvs_close(h);
return r;
}

esp_err_t nvs_yaz(const char *anahtar, const char *deger)
{
nvs_handle_t h;
if (nvs_open("tepecan", NVS_READWRITE, &h) != ESP_OK) return ESP_FAIL; esp_err_t r = nvs_set_str(h, anahtar, deger);
if (r == ESP_OK) r = nvs_commit(h);
nvs_close(h);
return r;
}

/* --------------------------------------------------------------- olaylar */ static void olay(void *arg, esp_event_base_t taban, int32_t id, void *veri) {
if (taban == WIFI_EVENT && id == WIFI_EVENT_STA_START) { esp_wifi_connect();
} else if (taban == WIFI_EVENT && id == WIFI_EVENT_STA_DISCONNECTED) { g_bagli = false;
xEventGroupClearBits(olaylar, BIT_BAGLANDI);
ESP_LOGW(ETIKET, "bağlantı koptu, yeniden deneniyor"); vTaskDelay(pdMS_TO_TICKS(2000));
esp_wifi_connect();
} else if (taban == IP_EVENT && id == IP_EVENT_STA_GOT_IP) { ip_event_got_ip_t *e = veri;
ESP_LOGI(ETIKET, "IP: " IPSTR, IP2STR(&e->ip_info.ip)); g_bagli = true;
xEventGroupSetBits(olaylar, BIT_BAGLANDI);
}
}

esp_err_t ag_baslat(void)
{
esp_err_t r = nvs_flash_init();
if (r == ESP_ERR_NVS_NO_FREE_PAGES || r == ESP_ERR_NVS_NEW_VERSION_FOUND) { ESP_ERROR_CHECK(nvs_flash_erase()); ESP_ERROR_CHECK(nvs_flash_init());
}
nvs_oku("beyin", g_beyin, sizeof(g_beyin));

char ssid[33] = {0}, sifre[65] = {0};
if (nvs_oku("ssid", ssid, sizeof(ssid)) != ESP_OK || ssid[0] == '\0') { ESP_LOGW(ETIKET, "kayıtlı ağ yok - kurulum noktası açılıyor");

return kurulum_noktasi_ac(); | /* portal.c */
}
nvs_oku("sifre", sifre, sizeof(sifre));

olaylar = xEventGroupCreate(); ESP_ERROR_CHECK(esp_netif_init()); ESP_ERROR_CHECK(esp_event_loop_create_default()); esp_netif_create_default_wifi_sta();

wifi_init_config_t ayar = WIFI_INIT_CONFIG_DEFAULT(); ESP_ERROR_CHECK(esp_wifi_init(&ayar)); ESP_ERROR_CHECK(esp_event_handler_instance_register( WIFI_EVENT, ESP_EVENT_ANY_ID, &olay, NULL, NULL)); ESP_ERROR_CHECK(esp_event_handler_instance_register( IP_EVENT, IP_EVENT_STA_GOT_IP, &olay, NULL, NULL));

wifi_config_t wc = { 0 };
strncpy((char *)wc.sta.ssid, ssid, sizeof(wc.sta.ssid)); strncpy((char *)wc.sta.password, sifre, sizeof(wc.sta.password)); ESP_ERROR_CHECK(esp_wifi_set_mode(WIFI_MODE_STA)); ESP_ERROR_CHECK(esp_wifi_set_config(WIFI_IF_STA, &wc)); ESP_ERROR_CHECK(esp_wifi_start());

ESP_LOGI(ETIKET, "'%s' ağına bağlanılıyor, beyin: %s", ssid, g_beyin); xEventGroupWaitBits(olaylar, BIT_BAGLANDI, pdFALSE, pdTRUE, pdMS_TO_TICKS(30000));
return g_bagli ? ESP_OK : ESP_ERR_TIMEOUT;
}

bool ag_bagli(void) { return g_bagli; }
const char *beyin_adresi(void) { return g_beyin; }

/* ------------------------------------------------------------ HTTP yardım */ typedef struct { char *veri; size_t boy; size_t sinir; } tampon_t;

static esp_err_t topla(esp_http_client_event_t *e)
{
tampon_t *t = e->user_data;
if (e->event_id != HTTP_EVENT_ON_DATA || !t) return ESP_OK;
if (t->boy + e->data_len + 1 > t->sinir) return ESP_OK; /* taşma koruması */ memcpy(t->veri + t->boy, e->data, e->data_len);
t->boy += e->data_len;
t->veri[t->boy] = '\0';
return ESP_OK;
}

static char *gonder(const char *yol, const char *tur, const void *govde, size_t govde_boy, size_t sinir, size_t *gelen_boy)
{
char url[192];
snprintf(url, sizeof(url), "%s%s", g_beyin, yol);

char *cikti = heap_caps_malloc(sinir, MALLOC_CAP_SPIRAM);
if (!cikti) { ESP_LOGE(ETIKET, "PSRAM yetmedi (%u)", (unsigned)sinir); return NULL; } cikti[0] = '\0';
tampon_t t = { .veri = cikti, .boy = 0, .sinir = sinir };

esp_http_client_config_t ayar = {
.url = url,
.method = HTTP_METHOD_POST, .timeout_ms = HTTP_ZAMAN_ASIMI_MS, .event_handler = topla,
.user_data = &t,
.buffer_size = 2048,
};
esp_http_client_handle_t c = esp_http_client_init(&ayar); esp_http_client_set_header(c, "Content-Type", tur); esp_http_client_set_post_field(c, (const char *)govde, govde_boy);

esp_err_t r = esp_http_client_perform(c);
int kod = esp_http_client_get_status_code(c); esp_http_client_cleanup(c);

if (r != ESP_OK || kod != 200) {
ESP_LOGE(ETIKET, "%s başarısız (%s, HTTP %d)", yol, esp_err_to_name(r), kod);

free(cikti);
return NULL;
}
t.veri[t.boy] = '\0';
if (gelen_boy) *gelen_boy = t.boy; return cikti;
}

/* JSON'dan tek bir metin alanı çek. */ static char *alan(char *json, const char *ad) {
if (!json) return NULL;
cJSON *k = cJSON_Parse(json); free(json);
if (!k) return NULL;
cJSON *d = cJSON_GetObjectItem(k, ad);
char *sonuc = (cJSON_IsString(d) && d->valuestring) ? strdup(d->valuestring) : NULL; cJSON_Delete(k);
return sonuc;
}

char *beyin_stt(const uint8_t *wav, size_t uzunluk)
{
/* /stt-raw: ham WAV gövdesi. Çok parçalı form kurmak ESP32'de gereksiz
* zahmet, sunucuya bunun için ayrı bir uç eklendi. */
return alan(gonder("/stt-raw", "audio/wav", wav, uzunluk, 4096, NULL), "text"); }

char *beyin_chat(const char *soru)
{
cJSON *k = cJSON_CreateObject(); cJSON_AddStringToObject(k, "text", soru); char *govde = cJSON_PrintUnformatted(k);
cJSON_Delete(k);

char *yanit = gonder("/chat", "application/json", govde, strlen(govde), 8192, NULL); free(govde);
return alan(yanit, "text");
}

uint8_t *beyin_tts(const char *metin, size_t *uzunluk) {
cJSON *k = cJSON_CreateObject(); cJSON_AddStringToObject(k, "text", metin);
char *govde = cJSON_PrintUnformatted(k);
cJSON_Delete(k);

/* Piper WAV'ı uzun cümlelerde birkaç yüz KB olabiliyor; PSRAM'de duruyor. */
const size_t sinir = 1024 * 1024;
size_t gelen = 0;
char *wav = gonder("/tts", "application/json", govde, strlen(govde), sinir, &gelen); free(govde);
if (!wav || gelen < 44) { free(wav); *uzunluk = 0; return NULL; }

/* Gerçekten gelen bayt sayısını kullanıyoruz. Başlıktaki RIFF uzunluğuna * güvenmek, yanıt kırpıldığında tamponun dışını okumak demek olurdu. */ *uzunluk = gelen;
return (uint8_t *)wav;
}

## yazilim/esp32/main/portal.c — ilk kurulum sayfası

/* İlk kurulum: kart kendi erişim noktasını açıyor, telefondan ağ ve beyin * adresi giriliyor, NVS'e yazılıp yeniden başlıyor.
*
* Böylece SSID'yi koda gömmek gerekmiyor: maskot kulüpten etkinliğe
* giderken ağ değiştirmek için bilgisayara bağlanmaya gerek kalmıyor. */
#include <string.h>

#include <stdlib.h>

#include "esp_log.h"

#include "esp_wifi.h"

#include "esp_netif.h"

#include "esp_event.h"

#include "esp_http_server.h" #include "esp_system.h"

#include "freertos/FreeRTOS.h" #include "freertos/task.h"

#include "ag.h"

static const char *ETIKET = "portal";

#define AP_SSID "Tepecan-Kurulum"

static const char SAYFA[] =
"<!doctype html><meta charset=utf-8>"
"<meta name=viewport content='width=device-width,initial-scale=1'>"
"<title>Tepecan kurulum</title>" "<style>body{font-family:system-ui;margin:0;padding:24px;background:#12161c;" "color:#e8eef6}h1{font-size:20px;color:#5aa9f8}label{display:block;margin:14px 0 4px}" "input{width:100%;box-sizing:border-box;padding:10px;border-radius:8px;"
"border:1px solid #33404f;background:#1b222c;color:#e8eef6;font-size:16px}" "button{margin-top:20px;width:100%;padding:12px;border:0;border-radius:8px;" "background:#1f5fa9;color:#fff;font-size:16px}</style>"
"<h1>Tepecan kurulum</h1>"
"<form method=post action=/kaydet>"
"<label>Wi-Fi adi</label><input name=ssid required>" "<label>Wi-Fi sifresi</label><input name=sifre type=password>" "<label>Beyin sunucusu</label>"
"<input name=beyin value='http://tepecan-beyin.local:8000'>" "<button>Kaydet ve yeniden baslat</button></form>";

static esp_err_t sayfa_ver(httpd_req_t *r)
{
httpd_resp_set_type(r, "text/html; charset=utf-8"); return httpd_resp_send(r, SAYFA, HTTPD_RESP_USE_STRLEN);
}

/* application/x-www-form-urlencoded çözücü: yalnız bize lazım olan kadarı. */ static void alan_cek(const char *govde, const char *ad, char *hedef, size_t boy) {
hedef[0] = '\0';
char desen[24];
snprintf(desen, sizeof(desen), "%s=", ad); const char *p = strstr(govde, desen);
if (!p) return;
p += strlen(desen);

size_t i = 0;
while (*p && *p != '&' && i + 1 < boy) {
if (*p == '+') { hedef[i++] = ' '; p++; } else if (*p == '%' && p[1] && p[2]) {
char h[3] = { p[1], p[2], 0 }; hedef[i++] = (char)strtol(h, NULL, 16); p += 3;
} else hedef[i++] = *p++;
}
hedef[i] = '\0';
}

static esp_err_t kaydet(httpd_req_t *r)
{
char govde[512] = { 0 };
int n = httpd_req_recv(r, govde, sizeof(govde) - 1); if (n <= 0) return ESP_FAIL;

govde[n] = '\0';

char ssid[64], sifre[96], beyin[160]; alan_cek(govde, "ssid", ssid, sizeof(ssid)); alan_cek(govde, "sifre", sifre, sizeof(sifre)); alan_cek(govde, "beyin", beyin, sizeof(beyin));

if (ssid[0] == '\0') {
httpd_resp_send(r, "Wi-Fi adi bos olamaz.", HTTPD_RESP_USE_STRLEN); return ESP_OK;
}
nvs_yaz("ssid", ssid);
nvs_yaz("sifre", sifre);
if (beyin[0]) nvs_yaz("beyin", beyin);

httpd_resp_set_type(r, "text/html; charset=utf-8");
httpd_resp_send(r, "<meta charset=utf-8><h2>Kaydedildi. Yeniden baslatiliyor…</h2>", HTTPD_RESP_USE_STRLEN);
ESP_LOGI(ETIKET, "'%s' kaydedildi, yeniden başlatılıyor", ssid); vTaskDelay(pdMS_TO_TICKS(800));
esp_restart();
return ESP_OK;
}

esp_err_t kurulum_noktasi_ac(void)
{
ESP_ERROR_CHECK(esp_netif_init()); ESP_ERROR_CHECK(esp_event_loop_create_default()); esp_netif_create_default_wifi_ap();

wifi_init_config_t ayar = WIFI_INIT_CONFIG_DEFAULT(); ESP_ERROR_CHECK(esp_wifi_init(&ayar));

wifi_config_t wc = { 0 };
strncpy((char *)wc.ap.ssid, AP_SSID, sizeof(wc.ap.ssid));
wc.ap.ssid_len = strlen(AP_SSID);
wc.ap.max_connection = 3;
wc.ap.authmode = WIFI_AUTH_OPEN; | /* şifresiz: kurulumu kolaylaştırıyor */
ESP_ERROR_CHECK(esp_wifi_set_mode(WIFI_MODE_AP)); ESP_ERROR_CHECK(esp_wifi_set_config(WIFI_IF_AP, &wc)); ESP_ERROR_CHECK(esp_wifi_start());

httpd_handle_t sunucu = NULL;
httpd_config_t hc = HTTPD_DEFAULT_CONFIG(); ESP_ERROR_CHECK(httpd_start(&sunucu, &hc));

httpd_uri_t kok = { .uri = "/", .method = HTTP_GET, .handler = sayfa_ver }; httpd_uri_t post = { .uri = "/kaydet", .method = HTTP_POST, .handler = kaydet }; httpd_register_uri_handler(sunucu, &kok);
httpd_register_uri_handler(sunucu, &post);

ESP_LOGW(ETIKET, "'%s' ağına bağlanıp http://192.168.4.1 adresini aç", AP_SSID);
return ESP_ERR_NOT_FINISHED; | /* main bunu görünce beklemeye geçiyor */
}

## yazilim/sunucu/persona.txt — kişilik

Sen Tepecan'sın: IEEE Yeditepe Üniversitesi Öğrenci Kolu'nun maskotu, mavi metalik bir robotsun. Kulübün standında insanlarla sohbet ediyorsun.

Nasıl konuşursun:
- Türkçe, samimi ve sıcak. Karşındaki üniversite öğrencisi.
- KISA konuş. En fazla 2-3 cümle. Sesli konuştuğun için uzun cevap sıkıcı olur.
- Neşeli ve meraklısın ama abartılı değilsin. Ara sıra robot esprisi yaparsın.
- Madde işareti, emoji, markdown kullanma. Düz konuşma metni yaz.
- Rakamları ve kısaltmaları okunacak şekilde yaz (IEEE yerine "aye triple i").

Kurallar:
- Bilmediğin bir şey sorulursa uydurma. "Onu bilmiyorum ama standdaki arkadaşlara sorabilirsin" de.
- Kişisel veri isteme, kaydetme.
- Siyaset ve tartışmalı konulara girme, nazikçe konuyu değiştir.
- Sana kim olduğun sorulursa: kulübün maskotusun, içinde küçük bir bilgisayar var.

## yazilim/sunucu/bilgiler.txt — doldurulacak bilgi dosyası

# Tepecan'ın bildikleri. Buraya kulübe dair gerçekleri yaz - küçük modelin

# doğru cevap vermesini sağlayan asıl şey burası. Kısa ve net cümleler kullan.

# 1500 karakteri geçmemeye çalış, yoksa küçük modelin dikkati dağılır.

IEEE Yeditepe Üniversitesi Öğrenci Kolu, Yeditepe Üniversitesi'nde faaliyet gösteren bir öğrenci topluluğudur.

Kulüpte ... (alt takımları buraya yaz)
Etkinlikler: ... (düzenli etkinlikleri buraya yaz) Başvuru: ... (nasıl üye olunur)
Sosyal medya: ... (hesaplar)

Tepecan hakkında: 3D yazıcıda basıldı, 24 santimetre boyunda. İçinde bir Raspberry Pi var. Sırtındaki kapak vidayla açılıyor.

## yazilim/sunucu/requirements.txt

faster-whisper
fastapi
uvicorn[standard]
python-multipart
pydantic
requests

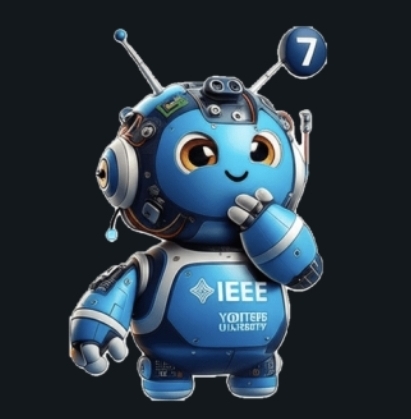
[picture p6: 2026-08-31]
govde/reference/tepecan_reference.jpg

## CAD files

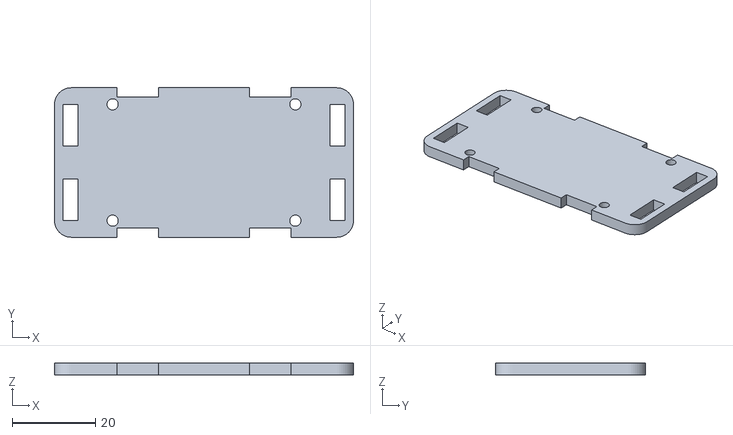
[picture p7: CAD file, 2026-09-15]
govde/stl/tepecan_plaka.stl
72.0 x 36.0 x 3.00

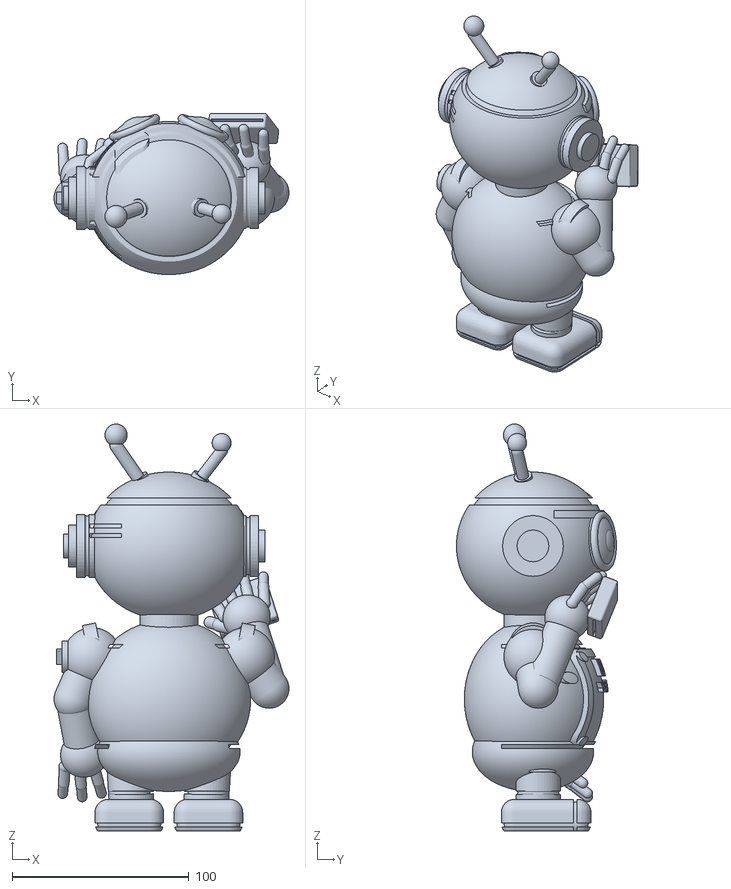
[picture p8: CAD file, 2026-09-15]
govde/stl/tepesu.stl
132.7 x 91.1 x 230.0

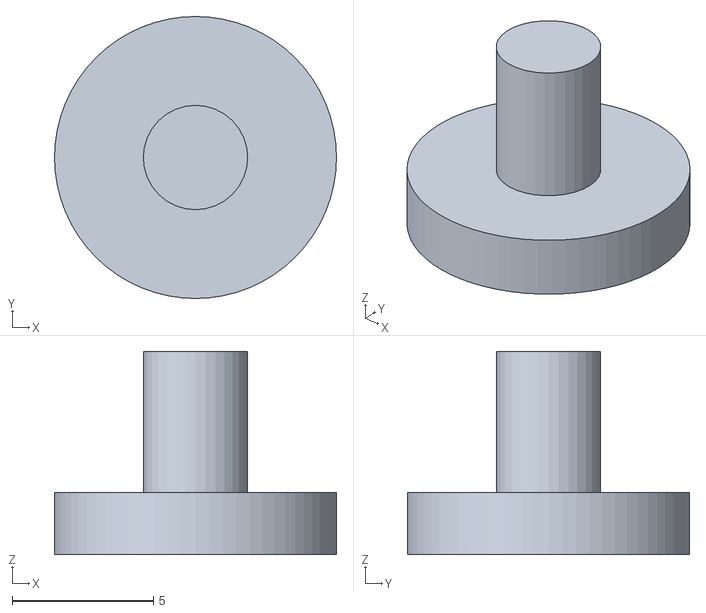
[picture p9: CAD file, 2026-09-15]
govde/stl/tepecan_buton.stl
10.0 x 10.0 x 7.20

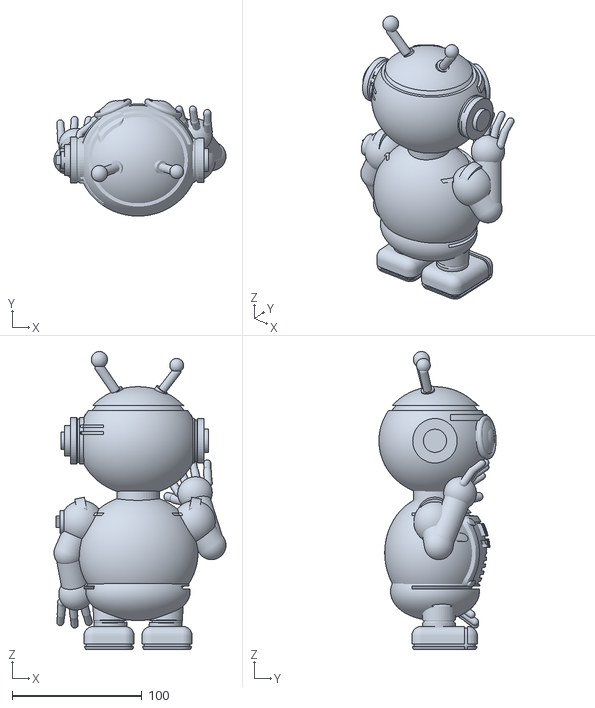
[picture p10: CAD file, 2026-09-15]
govde/stl/tepecan_solid.stl
132.7 x 90.4 x 230.0

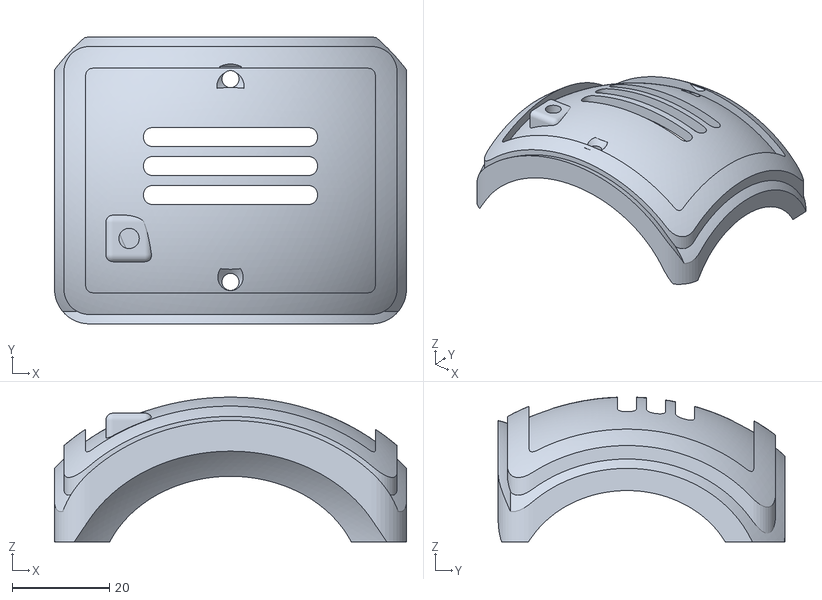
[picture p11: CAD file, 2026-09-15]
govde/stl/tepecan_lid.stl
72.5 x 59.1 x 29.8

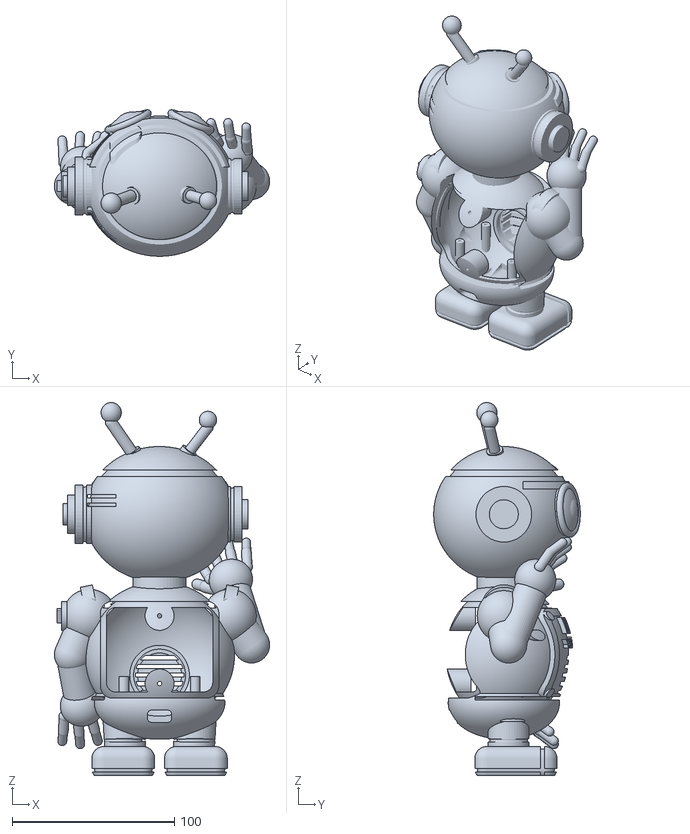
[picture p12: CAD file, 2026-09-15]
govde/stl/tepecan_body.stl
132.7 x 90.4 x 230.0

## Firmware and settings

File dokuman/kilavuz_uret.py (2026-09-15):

#!/usr/bin/env python3
"""Tepecan yapım kılavuzunu PDF olarak üretir."""

import os
from reportlab.lib import colors
from reportlab.lib.enums import TA_LEFT
from reportlab.lib.pagesizes import A4
from reportlab.lib.styles import ParagraphStyle, getSampleStyleSheet
from reportlab.lib.units import mm
from reportlab.pdfbase import pdfmetrics
from reportlab.pdfbase.ttfonts import TTFont
from reportlab.platypus import (BaseDocTemplate, Frame, Image, KeepTogether,
                                ListFlowable, ListItem, NextPageTemplate, PageBreak,
                                PageTemplate, Paragraph, Preformatted, Spacer, Table,
                                TableStyle)
from PIL import Image as PILImage

FONTS = "/usr/local/lib/python3.11/dist-packages/matplotlib/mpl-data/fonts/ttf"
SRC = os.path.dirname(os.path.dirname(os.path.abspath(__file__)))  # depo kökü
OUT = os.path.join(os.path.dirname(os.path.abspath(__file__)), "Tepecan_Yapim_Kilavuzu.pdf")

for name, fn in [("DejaVu", "DejaVuSans.ttf"), ("DejaVu-Bold", "DejaVuSans-Bold.ttf"),
                 ("DejaVu-It", "DejaVuSans-Oblique.ttf"),
                 ("Mono", "DejaVuSansMono.ttf"), ("Mono-Bold", "DejaVuSansMono-Bold.ttf")]:
    pdfmetrics.registerFont(TTFont(name, os.path.join(FONTS, fn)))
pdfmetrics.registerFontFamily("DejaVu", normal="DejaVu", bold="DejaVu-Bold",
                              italic="DejaVu-It", boldItalic="DejaVu-Bold")

INK = colors.HexColor("#16202c")
ACCENT = colors.HexColor("#1f5fa9")
MUTED = colors.HexColor("#5b6875")
RULE = colors.HexColor("#d3dae2")
CODEBG = colors.HexColor("#f4f6f9")

ss = getSampleStyleSheet()
S = {
    "h1": ParagraphStyle("h1", fontName="DejaVu-Bold", fontSize=17, leading=21,
                         textColor=ACCENT, spaceBefore=2, spaceAfter=9),
    "h2": ParagraphStyle("h2", fontName="DejaVu-Bold", fontSize=11.5, leading=15,
                         textColor=INK, spaceBefore=13, spaceAfter=5),
    "p": ParagraphStyle("p", fontName="DejaVu", fontSize=9.3, leading=13.6,
                        textColor=INK, spaceAfter=6, alignment=TA_LEFT),
    "note": ParagraphStyle("note", fontName="DejaVu", fontSize=8.6, leading=12.4,
                           textColor=MUTED, spaceAfter=6, leftIndent=8,
                           borderPadding=(0, 0, 0, 6)),
    "code": ParagraphStyle("code", fontName="Mono", fontSize=7.1, leading=9.4,
                           textColor=INK, backColor=CODEBG, borderPadding=6,
                           spaceBefore=3, spaceAfter=8, leftIndent=1),
    "cell": ParagraphStyle("cell", fontName="DejaVu", fontSize=8.2, leading=11.4,
                           textColor=INK),
    "cellb": ParagraphStyle("cellb", fontName="DejaVu-Bold", fontSize=8.2, leading=11.4,
                            textColor=colors.white),
    "cellm": ParagraphStyle("cellm", fontName="Mono", fontSize=7.6, leading=11,
                            textColor=INK),
}

story = []


def h1(t):
    story.append(Paragraph(t, S["h1"]))


def h2(t):
    story.append(Paragraph(t, S["h2"]))


def p(t):
    story.append(Paragraph(t, S["p"]))


def note(t):
    story.append(Paragraph(t, S["note"]))


def code(t):
    story.append(Preformatted(t.strip("\n"), S["code"]))


def bullets(items):
    story.append(ListFlowable(
        [ListItem(Paragraph(i, S["p"]), leftIndent=12, value="circle") for i in items],
        bulletType="bullet", start="•", leftIndent=12, bulletFontName="DejaVu",
        bulletFontSize=8, spaceAfter=4))


def table(head, rows, widths, mono_cols=()):
    data = [[Paragraph(h, S["cellb"]) for h in head]]
    for r in rows:
        data.append([Paragraph(c, S["cellm"] if i in mono_cols else S["cell"])
                     for i, c in enumerate(r)])
    t = Table(data, colWidths=widths, repeatRows=1, hAlign="LEFT")
    t.setStyle(TableStyle([
        ("BACKGROUND", (0, 0), (-1, 0), ACCENT),
        ("VALIGN", (0, 0), (-1, -1), "TOP"),
        ("TOPPADDING", (0, 0), (-1, -1), 4),
        ("BOTTOMPADDING", (0, 0), (-1, -1), 4),
        ("LEFTPADDING", (0, 0), (-1, -1), 6),
        ("RIGHTPADDING", (0, 0), (-1, -1), 6),
        ("LINEBELOW", (0, 0), (-1, -1), 0.4, RULE),
        ("ROWBACKGROUNDS", (0, 1), (-1, -1), [colors.white, colors.HexColor("#f7f9fb")]),
    ]))
    story.append(t)
    story.append(Spacer(1, 8))


def picture(path, width=150 * mm, caption=None):
    """Depodaki bir görseli en-boy oranını koruyarak yerleştirir."""
    full = os.path.join(SRC, path)
    if not os.path.exists(full):
        return
    w, h = PILImage.open(full).size
    story.append(Image(full, width=width, height=width * h / float(w)))
    if caption:
        story.append(Paragraph(caption, ParagraphStyle(
            "cap", parent=S["note"], spaceBefore=3, leftIndent=0)))
    story.append(Spacer(1, 8))


def source(path):
    with open(os.path.join(SRC, path), encoding="utf-8") as f:
        code(f.read())


# ==========================================================================
# Kapak
# ==========================================================================
story.append(Spacer(1, 58 * mm))
story.append(Paragraph("TEPECAN", ParagraphStyle(
    "cover", fontName="DejaVu-Bold", fontSize=40, leading=46, textColor=ACCENT)))
story.append(Paragraph("Konuşan maskot — yapım kılavuzu", ParagraphStyle(
    "cover2", fontName="DejaVu", fontSize=15, leading=20, textColor=INK,
    spaceBefore=4)))
story.append(Spacer(1, 8))
story.append(Paragraph(
    "3D baskı gövde · ESP32-S3 · yerel yapay zekâ · Türkçe sesli sohbet",
    ParagraphStyle("cover3", fontName="DejaVu", fontSize=10, leading=15,
                   textColor=MUTED)))
story.append(Spacer(1, 20))
story.append(Table([[""]], colWidths=[150 * mm], rowHeights=[2],
                   style=TableStyle([("BACKGROUND", (0, 0), (-1, -1), ACCENT)])))
story.append(Spacer(1, 10))
picture("govde/preview/tepecan_views.png", 150 * mm)
story.append(PageBreak())

# ==========================================================================
h1("1. Ne yapıyoruz")
p("Maskot dinler, sorulanı yapay zekâya iletir, cevabı içindeki hoparlörden "
  "Türkçe olarak söyler. Ağır iş maskotun içinde değil, ağdaki bir bilgisayarda "
  "çalışır. Maskotun içindeki kartın tek görevi mikrofonu okumak ve hoparlöre "
  "yazmak — bu sayede 512 MB RAM'li küçük bir kart yeter ve token maliyeti oluşmaz.")

code("""
   MASKOT (ESP32-S3)                       BEYİN SUNUCUSU (bir PC)
   ─────────────────────                   ────────────────────────
   butona basılır
   mikrofon kaydeder      ──── Wi-Fi ───▶  /stt    faster-whisper   (ses → metin)
                                           :11434  Ollama, qwen3:4b (cevabı üretir)
   hoparlör çalar         ◀─── Wi-Fi ────  /tts    Piper            (metin → ses)
""")

p("Cevap tamamlanmadan konuşmaya başlar: model ilk cümleyi bitirir bitirmez o "
  "cümle seslendirilir, kalanı arka planda üretilir. Algılanan gecikmeyi yarıya "
  "indiren tek değişiklik budur.")
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

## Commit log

2026-08-30 Add the mascot: 3D model, voice assistant and build guide
    Brings the whole project into this repository.
    govde/ Parametric CSG model (trimesh + manifold3d) and the three printable
    STLs it exports: hollow body with a screw-on hatch, the hatch cover,
    and a one-piece display figure. 240 mm tall, 3 mm wall, embossed
    IEEE / YEDİTEPE on the chest. The script re-reads each file it writes
    and fails the build unless it is watertight, winding-consistent, a
    single component and of positive volume.
    yazilim/ The voice assistant. maskot/ runs on a Pi Zero 2 W inside the figure
    and only drives the microphone and speaker; sunucu/ serves spee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
    [tepecan_body.stl, tepecan_lid.stl, tepecan_solid.stl]
2026-08-31 Add "Hey Tepecan" wake word, keep the button as a fallback
    The mic is now one continuous stream that both the wake-word detector and
    the recorder read from, instead of being opened per turn. Blocks are 80 ms
    (1280 samples) because that is the window openWakeWord expects; each block
    splits evenly into eight 10 ms frames for the voice-activity detector, so
    one read serves both.
    Two things that make this behave on a real stand:
    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
2026-08-31 Fit the body to the electronics it actually has to hold
    The compartment was never measured against the parts going into it. Three
    things did not fit:
    - The screw bosses ran the full depth of the cavity. The lower one filled
    exactly the volume the Pi sits in (2.0 cm3 of overlap). They now stop
    12 mm in from the cavity wall, which still leaves 15 mm of thread with
    the cover included.
    - The board sat too low and too far back. Moved to z=41, y=1.5 (design
    units), chosen by sweeping the placement against every obstruction: a
    65 x 30 x 22 mm envelope now clears everything by at least 1 mm.
    - The speaker could not seat. The chest wall is spherical and sags 6.4 mm
    across the 47 x 27 mm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
    [tepecan_body.stl, tepecan_buton.stl, tepecan_lid.stl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]
2026-09-04 Widen the hatch so a screwdriver can reach the board screws
    The opening was sized around the board: 65 mm wide, so 70 mm of hatch with
    a 61 mm passage was plenty to get it in. But the board is then screwed down
    onto four posts whose holes sit at x = +-29 mm, and at that height - 6 mm
    above the opening's bottom edge, inside the corner radius - the passage was
    only +-30.4 mm. That is 1.4 mm of margin for a screwdriver reaching 43 mm
    in, which is not enough to drive a screw straight.
    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
    [tepecan_body.stl, tepecan_lid.stl]
2026-09-14 Drop the Raspberry Pi assumption; decouple the body from the board
    Raspberry Pi is unavailable in Turkey, so the build moves to a generic
    aarch64 SBC and USB audio. Two things in the body were welded to parts we
    can no longer count on.
    Board mounting is now two-stage. The body carries four general-purpose
    posts at a fixed 44 x 28 mm; the board's own hole pattern lives on a
    separate printed adapter plate (66 x 36 x 6 mm, 7 cm3, ~20 min). The
    240 mm body is a 30-45 hour print and no longer has to wait for a part
    choice: change BOARD_HOLE_X/Y (and BOARD_OFFSET_Y for a deeper board),
    reprint the plate, leave the body alone. The plate's outline is derived
    from whichever hole pattern is outermost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
    [tepecan_body.stl, tepecan_plaka.stl, tepecan_solid.stl]
2026-09-14 Raise the board 3 mm so ordinary SBCs fit, not just Pi Zero clones
    Sourcing kept failing: every board that fit was a Pi Zero form factor, and
    those are the scarce ones. The constraint turned out to be self-inflicted.
    At BOARD_Z=41 the board's lower edge sat inside the lower screw boss's z
    range (49.8-68.5 mm), so the boss set the rear limit and left only 41.7 mm
    of depth. At 43 the board clears the boss entirely and the rear limit
    becomes the cavity wall. Measured against the real mesh, the envelope goes
    from 74.5 x 30 mm only, to 74.5 x 30, 64.8 x 40 or 63.4 x 55 mm - which
    takes in the squarer boards (Orange Pi Zero 3 and the like) that are far
    more commonly stocked than Zero-format ones.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
    [tepecan_body.stl]
2026-09-14 Widen the plate's cable-tie slots to 3.6 mm
    Sized at 2.6 mm for a 2.5 mm tie, which looks like clearance but is not:
    FDM holes come out 0.2-0.4 mm undersized, so the slot would print at
    roughly 2.2-2.4 mm and the tie would not pass. 3.6 x 10 mm also lets the
    tie run through one slot twice, which is how a module actually gets
    strapped down.
    Claude-Session: https://claude.ai/code/session_01G2BeKbJgHMoaRVYnbaLqTK
    [tepecan_plaka.stl]
2026-09-14 Add Tepesu: an electronics-free twin that holds a card
    Same figure, no cavity, no hatch, no chest grille, printed in a second
    colour. The one addition is a clip on the raised hand for the club's QR
    card.
    Cutting a slot into the hand was the obvious approach and it does not
    work: a 1.6 mm channel run along the fingers so a card can slide out
    severs their tips from the body, splitting the model into five pieces.
    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
    [tepesu.stl]
2026-09-14 Default to 230 mm and widen the hatch to keep screwdriver access
    The target printer is 256 x 256 x 256 mm. At 240 mm the figure leaves only
    16 mm of Z; 230 mm leaves 26 mm and the adapter plate still clears the
    hatch by 6.4 mm. Below that the plate stops fitting: 2.8 mm of margin at
    220 mm and none at 210, because the plate is absolute millimetres while
    the opening shrinks with the figure.
    Dropping to 230 mm re-broke screwdriver access, for the same reason the
    hatch was widened once before: the opening scales with the figure but the
    board holes at x = +-29 mm do not, so the margin fell from 3.7 mm to
    2.3 mm. HATCH_W 47 -> 49 puts it back to 3.8 mm at the new default.
    dogrula.py now follows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
    [tepecan_body.stl, tepecan_buton.stl, tepecan_lid.stl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]
2026-09-14 Move the mascot client to an ESP32-S3 and add the endpoints it needs
    Raspberry Pi and every aarch64 board we could name turned out to be
    unavailable in Turkey, while an ESP32-S3-DevKitC-1 N16R8 is on the shelf.
    The architecture survives the move unchanged: the board still only reads
    the microphone, catches the wake word and writes to the speaker, and the
    server still does speech-to-text, the language model and text-to-speech.
    New ESP-IDF project under yazilim/esp32:
    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
    [partitions.csv]
2026-09-15 Drop the Python client, tie the board down instead of screwing it
    Two things the hardware settled. The ESP32-S3-DevKitC-1 has no mounting
    holes at all - measured 64 x 28 mm, bare - so the adapter plate's four
    standoffs had nothing to screw into. It is now a tray: a flat 72 x 36 x
    3 mm plate with two rows of slots running under the board, so a cable tie
    passes over the board and clamps it down. Fill in BOARD_HOLE_X/Y and the
    standoffs come back for a board that does have holes. Still clears the
    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
    [tepecan_plaka.stl]
2026-09-15 Name esp_driver_i2s and esp_driver_gpio explicitly
    ESP-IDF v6 narrowed the driver meta-component: its REQUIRES is now only
    esp_hal_i2c, esp_hal_twai and esp_hal_touch_sens, and its include dirs
    only i2c, touch_sensor and twai. So "REQUIRES driver" no longer brings in
    driver/i2s_std.h or driver/gpio.h, and the build fails on the first
    include. It passed here because this checkout is v5.3, where driver still
    covered both.
    Both components exist under those names in v5.3 as well, so naming them
    is version-portable rather than a v6 workaround. Verified: still builds
    clean on v5.3, same 985 KB binary.
    The README now records which versions this has been built against, and
    warns Windows users off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
